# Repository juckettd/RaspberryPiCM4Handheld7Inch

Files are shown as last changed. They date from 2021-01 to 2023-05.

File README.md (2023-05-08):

# Raspberry Pi CM4 Handheld 7 - Aegis"

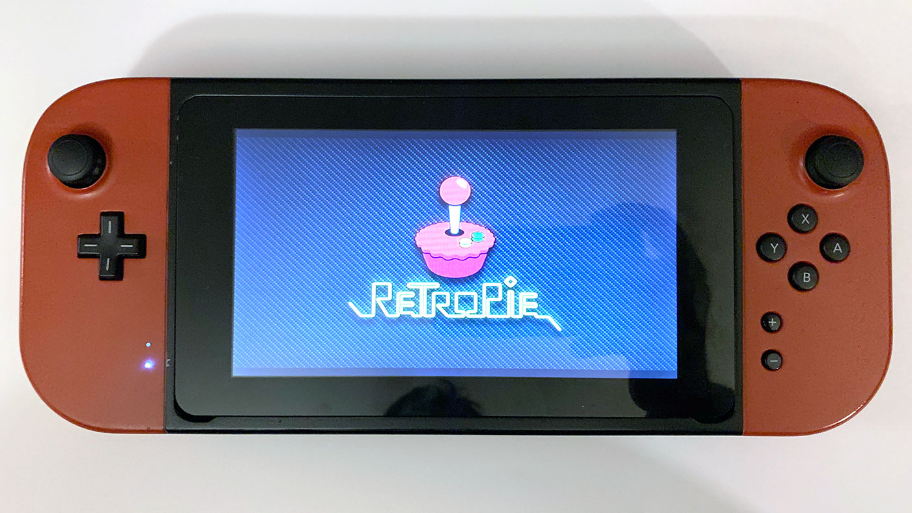
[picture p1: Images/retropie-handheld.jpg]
RetroPie running on Raspberry Pi CM4 Handheld
<p align="center"></p>

A repository for the Aegis, a 7" Raspberry Pi CM4 handheld device.

NOTE: This is still a work in progress. The design has been finalized but I'm still working on the instructions, therefore there might be steps that are missing at this moment.

## Summary

The Aegis is a DIY handheld that uses a 3D printed case with a Raspberry Pi CM4 and the official Raspberry Pi 7" screen. The official Raspberry Pi screen was chosen because it uses the DSI port on the Raspberry Pi and the CM4 could fit on either side of the display board. While a Raspberry Pi 4 might have fit inside the case, that was eventually designed, a custom carrier board was used to place the ports in the desired locations. To facilitate the controller portion of the device, the Wii U buttons and joysticks were used. This made it easy to use the button sub-assemblies so that the same tactile feel of the buttons could be maintained. The 3D printed case was based on the Wii U Gamepad but still designed from the ground up to fit the 7" screen and the custom circuit board. Finally, the whole thing was assembled with speakers and rumble motors to complete the handheld.

## Building the Handheld

To build the handheld you will need the items listed as required in the Bill of Materials along with the following tools:

Reflow Station or Reflow Oven<br/>
Solding Iron<br/>
Solder Paste<br/>
Tweezers<br/>
Small Philips Screw Driver<br/>
Small Flathead Screw Driver<br/>
Super Glue (preferrably CA glue with Accelerator)

There are items in the Bill of Materials that are listed as optional (such as the Wifi chip). These items are not required to get a working device but can be used if desired. At this time I will not provide directions on how to use the optional components so use at your discretion.

### Assembling the Circuit Board

The custom circuit boards are provided as eagle files in this repository. This includes the schematic, board layout, and the gerber files. 

To get the boards printed, a manufacturing facility is required. The website jlcpcb.com was used to print the 2 circuit board prototypes for the design. The larger of the two boards uses 4 layers, and the smaller one uses only 2 layers. It is recommended to also get the stencils with the boards so that applying the solder paste becomes much easier.

Once the boards have been received you will need to assemble the circuitry on the boards. This is done by getting all of the components provided in the bill of materials in the "PCB Components" sheet. Each item has a provided Link to where the item can be acquired along with the price at the time of the assembly of the prototype. After acquiring all of the components, use the stencil to apply solder paste to the circuit boards and then use tweezers to place each component. A reflow oven or reflow station should then be used to melt the solder paste and adhere the components. Lastly, any through hole components were then added on the using a soldering iron. 

Note: The teensy that is soldered to the board using the through holes. However, there are 4 pads that are located near the USB connector of the Teensy on the custom circuit board. They are the VBUS, D+, D-, and GND connections. I included the VBUS and GND connections as backups but they are not needed as the power and ground comes from the pins. But the D+, D- connections need to be connected to the teensy. On the underside of the teensy there are 4 pads that are in about the same location, a wire or some other form of connection is needed to connect the D+ from the teensy to the D+ on the custom circuit board, do the same with the D- connection.

While anyone who has experience with circuit boards will have their own method for assembling these boards I used the following steps and it is what I recommend for anyone without experience and a reflow oven (but a reflow station is required):
1. Using the stencil, put solder paste on the larger of the two boards on the side with a majority of the components
2. Place all of the surface mount components on that side of the board
3. Use a reflow station and heat the underside of the board until the solder paste on the top side melts to adhere the components. A tool to prop up the PCB comes in handy here. In my opinion this part is essential as some of the components are plastic and the hot air coming out of a reflow station can melt them.
4. Use a soldering iron to clean up an connections that didn't connect completely (You can watch youtube videos on how to do this, just search for solding iron and surface mount components)
5. Flip the board over and redo steps 1-4 for the underside of the board. Since these components are larger I just used the a soldering iron for all of the components, but the same procedure with the reflow station can be used. Just be careful with the hot air hitting components you have already put down, as they can fall off if the solder paste melts again.
6. Perform 1-5 for the second board and the few surface mount components that are on that board
7. Add all of the through hole items to both boards with a soldering iron (again youtube is your friend)

### Install Teensy Code

Before (or after) the circuit board has been assembled the teensy code needs to be pushed to the teensy. The teensy code is provided in the repo and you will need to follow the instructions on the teensy website for pushing code. Make sure that you set the board type to "XInput" otherwise it won't be seen as a XBox 360 Controller.

### 3D Printed Case

The files provided here and on Thingiverse are STL files for the case. They are printed in sections so that a printer with a standard bed size of 220mm x 220mm can be used print the case (I also provided the pieces combined for larger printers). Once they are printed they will have to be cleaned up and then glued together. Depending on which angle you choose to print the parts the cleanup step could be more or less cumbersome for the remove of support and getting good glue joints. I choose to print everything with flat surfaces on the bed to keep the post processing steps as easy as possible.

Once everything is glued together then no post processing is technically required to assemble the device. However, I chose to use filler, sand paper, and paint to get a really clean looking finish. The level of detail you desire on your handheld will be up to you based on how much effort you want to devote. Refer to youtube for how to sand and paint a 3D printed piece. However, try to keep the inside of the device as paint free as possible as the internal structure is already at the correct dimensions for the internal components.

I would also sand down the holes where the buttons will be located as they will to be rough from the 3D printing process. This can cause the buttons to stick.

Thingiverse link:
https://www.thingiverse.com/thing:4789405

### Assembly

Once the case and the PCB have been built and are ready to go the handheld can be assembled.

See the assembly instructions file provided with detailed instructions and pictures.

## Software

The carrier board was designed with the option of either using the CM4 lite or the CM4 with onboard memory. If the lite is used then a micro SD card is required. Follow the instructions on the official Raspberry Pi website or the RetroPie website to get the desired OS installed on the micro SD card. If the lite is not used then the internal memory can be loaded by removing the panel on the back of the handheld held and flipping the switch to the "ON" position. You can then use the micro USB port to load the CM4. Please refer to the official Raspberry Pi website on these steps. Once the OS is loaded then unplug the cable and flip the switch back to the off position.

### /boot/config.txt

Regardless of which CM4 you use and which method is used to load the OS, you will need to add the following lines to the /boot/config.txt file. These are also listed in the /Config/boot/config.txt file in this repository:

dtoverlay=dwc2,dr_mode=host<br/>
gpu_mem_256=128<br/>
gpu_mem_512=256<br/>
gpu_mem_1024=256<br/>
force_turbo=1<br/>
h264_freq=333

The lines above will optimize the graphics for Moonlight (if you choose to use it to stream PC games) and will enable USB 2.0 on the device to get the Teensy and external USB ports working.

### First Boot

For the first boot you will need to plug in a HDMI cord into the HDMI mini port. This is required since the screen won't work yet. Once it boots you need to connect to Wifi or Ethernet through whatever OS you have installed and run the following commands (also listed in the Config folder):

sudo apt install python3-gpiozero<br/>
sudo apt install python3-smbus<br/>
sudo wget https://goo.gl/iiVxuA -O /boot/dt-blob.bin

These will install required packages for a system monitor script and will also install the dt-blob.bin file to get the screen working. Once this is complete reboot the handheld and unplug the HDMI cord. The device will automatically switch to the screen on the reboot.

### System Setup

After the first boot and subsequent reboot you can either use git to download the items from the Config folder in this repository or you can copy the files to a USB stick and load them through the USB ports. Once on your Raspberry Pi, navigate to wherever you have loaded the files and run the setup.sh script as follows:

sudo bash ./setup.sh

This script will install files onto your Raspberry Pi to handle a series of things including:

Provide a startup script to detect when the HDMI cord is plugged in and switch to that output<br/>
Enable the buttons on the device to work<br/>
Enable sound through the speakers<br/>
Generating an overlay on the screen to give battery life, wifi status, bluetooth status, etc...<br/>
Provide a safe shut down proceedure for when the power button is pressed<br/>

Once the setup script is run the files you downloaded may be deleted.

## Have Fun

At this point the device should be fully up and running on whatever OS you decided to use. I suggest you start playing games and have fun :)

## Pictures/Videos

Images of the prototype are included if you want to see what a final version can look like and here is a list of youtube links for demoes on the device in operation:

Raspberry Pi CM4 Handheld - PC Games Demo
https://youtu.be/qqAcT7MvEfQ

Raspberry Pi CM4 Handheld - Pixel Desktop Logout
https://youtu.be/YUHz1qglbvk

Raspberry Pi CM4 Handheld - Touchscreen Demo
https://youtu.be/fQMbkvToMkI

Raspberry Pi CM4 Handheld - Youtube Video Showing Sound Quality
https://youtu.be/o1zs3FDNwGw

Raspberry Pi CM4 Handheld - Donkey Kong Country 2
https://youtu.be/sit6ItH9wHg

Raspberry Pi CM4 Handheld - Prototype Test
https://youtu.be/XAPKUmwa3sU

## Credits

To get the script and overlay down I took parts of the following work and adapted it to what I needed. But these projects deserve most of the credit for what they already did.

GBZ_Overlay 
https://github.com/d-rez/gbz_overlay

Pngview
https://github.com/AndrewFromMelbourne/raspidmx/tree/master/pngview

Safe shutdown script
https://github.com/crcerror/ES-generic-shutdown/blob/master/multi_switch.sh

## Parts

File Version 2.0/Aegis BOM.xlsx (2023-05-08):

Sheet: PCB Components
Item | Component | Qty | Price | Total | Link
Power Items
Battery Charging IC | BAT_CHR | 1 | $3.76 | $3.76 | https://www.digikey.com/product-detail/en/texas-instruments/BQ25895RTWT/296-41132-1-ND/5218172
5V Boost IC | 5V_REG | 1 | $2.68 | $2.68 | https://www.digikey.com/en/products/detail/texas-instruments/TPS61030PWPR/550685
3.3V Buck/Boost IC | 3.3V_REG | 1 | $2.34 | $2.34 | https://www.digikey.com/en/products/detail/texas-instruments/TPS63001DRCR/1016512
2 pin Connection Header | BAT_CONN | 1 | $0.17 | $0.17 | https://www.digikey.com/product-detail/en/jst-sales-america-inc/S2B-XH-A-LF-SN/455-2257-ND/1651055
2 pin Connection Housing | BAT_PLUG | 1 | $0.10 | $0.10 | https://www.digikey.com/product-detail/en/jst-sales-america-inc/XHP-2/455-2266-ND/555485
Jumper Wires | BAT_WIRES | 1 | $0.76 | $0.76 | https://www.digikey.com/product-detail/en/jst-sales-america-inc/ASXHSXH22K152/455-3240-ND/6684931
USB-C Socket (PWR) | USB_PWR | 1 | $1.26 | $1.26 | https://www.digikey.com/en/products/detail/adam-tech/USB-C31-S-RA-CS1D-BK-T-R/9832218
Fuel Gauge | FUELGAUGE | 1 | $3.15 | $3.15 | https://www.digikey.com/en/products/detail/analog-devices-inc-maxim-integrated/MAX17055ETB-T/7200799
Audio Items
UDA1334A | AUDIO_DAC | 1 | $0.25 | $0.25 | https://www.aliexpress.com/item/33049485687.html?spm=a2g0s.9042311.0.0.1b124c4d3HPSEF
MAX98306ETD+T | AUDIO_AMP | 1 | $1.91 | $1.91 | https://www.digikey.com/en/products/detail/maxim-integrated/MAX98306ETD-T/2708795
Headphone Jack | AUDIO_PLUG | 1 | $1.38 | $1.38 | https://www.digikey.com/product-detail/en/adam-tech/ASJ-192-Y-T-R/2057-ASJ-192-Y-T-RCT-ND/9833145
USB Items
USB 2 Port Stacked | USB_CONN | 1 | $5.76 | $5.76 | https://www.digikey.com/en/products/detail/w%C3%BCrth-elektronik/614108646521/11627306
USB Hub 4-port | USB_HUB | 1 | $3.05 | $3.05 | https://www.digikey.com/en/products/detail/microchip-technology/USB2514BT-I-M2/9923870
USB Current Limit | USB_CURLIM | 1 | $0.42 | $0.42 | https://www.digikey.com/en/products/detail/diodes-incorporated/AP22653W6-7/10481188
24MHz Crystal | CLK_24M | 1 | $0.39 | $0.39 | https://www.digikey.com/en/products/detail/ecs-inc/ECS-240-9-33B-CTP-TR/12349443
USB POE Protection | USB_POE | 1 | $0.79 | $0.79 | https://www.digikey.com/en/products/detail/texas-instruments/TPD4EUSB30DQAR/2503665
USB Host/Slave Switch | USB_SWI | 1 | $0.60 | $0.60 | https://www.digikey.com/en/products/detail/on-semiconductor/FSUSB42MUX/2036916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
USB Micro Input | USB_IN | 1 | $0.76 | $0.76 | https://www.digikey.com/en/products/detail/gct/USB3131-30-0230-A/9859642
RPI Boot Switch | RPI_BOOT_SW | 1 | $0.91 | $0.91 | https://www.digikey.com/en/products/detail/omron-electronics-inc-emc-div/A6TN-1104/2754763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
HDMI Items
HDMI Socket | HDMI_CONN | 1 | $1.73 | $1.73 | https://www.digikey.com/en/products/detail/cnc-tech/2001-1-2-21-00-BK/4867021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
HDMI Current Limit | HDMI_CURLIM | 1 | $0.51 | $0.51 | https://www.digikey.com/en/products/detail/diodes-incorporated/AP2331W-7/4251553
LCD Items
FPC Connector | LCD_CONN | 1 | $0.95 | $0.95 | https://www.digikey.com/en/products/detail/te-connectivity-amp-connectors/1-84952-5/2272419
Micro SD Items
Micro SD Socket | MICROSD | 1 | $2.41 | $2.41 | https://www.digikey.com/product-detail/en/molex/5033981892/WM11190CT-ND/5230912
Micro SD Power Switch | MICROSD_SWI | 1 | $1.52 | $1.52 | https://www.digikey.com/en/products/detail/richtek-usa-inc/RT9742GGJ5/5880519
Ethernet
Ethernet Port | ETH_CONN | 1 | $8.21 | $8.21 | https://www.digikey.com/en/products/detail/kycon-inc/GLPLX-SMT-188S7-QQ-Y-G/9990208
Board Connectors
Mezzanine Connector (RP4) | RPI_PINR1-100, RPI_PINS101-200 | 2 | $1.73 | $3.46 | https://www.digikey.com/en/products/detail/hirose-electric-co-ltd/DF40C-100DS-0-4V-51/1969476
Mezzanine Connector (Top Ports Board) | BOARD_CONN_2 | 1 | $1.36 | $1.36 | https://www.digikey.com/en/products/detail/panasonic-electric-works/AXT530124/1986604
Mezzanine Header (Main Board) | BOARD_CONN_1 | 1 | $1.86 | $1.86 | https://www.digikey.com/en/products/detail/panasonic-electric-works/AXT630124/1986595
Speaker/Motor Connector | SPK_CONN, MOT_CONN | 2 | $0.65 | $1.30 | https://www.digikey.com/en/products/detail/jst-sales-america-inc/S4B-ZR-SM4A-TF-LF-SN/926602
Speaker/Motor Jumper | SPK_WIRE, MOT_WIRE | 2 | $1.79 | $3.58 | https://www.digikey.com/en/products/detail/jst-sales-america-inc/A04ZR04ZR28H305A/6009406
Fan Connector | FAN_CONN | 1 | $1.25 | $1.25 | https://www.digikey.com/en/products/detail/te-connectivity-amp-connectors/282834-2/1150135
LCD Power Connector | LCD_PWR_CONN | 1 | $0.19 | $0.19 | https://www.digikey.com/en/products/detail/amphenol-icc-fci/68016-402HLF/1658021
Button Connector | BUTL_CONN, BUTR_CONN | 2 | $1.73 | $3.46 | https://www.digikey.com/product-detail/en/hirose-electric-co-ltd/FH52-10S-0-5SH/H126109CT-ND/9489678
Buttons
Buttons | BUT_PWR, BUT_MISC, BUT_VOL_UP, BUT_VOL_DOWN | 4 | $0.65 | $2.60 | https://www.digikey.com/en/products/detail/c-k/KSS331GLFS/417674?s=N4IgTCBcDaINIGUEGZkEYDiAZAYgkAugL5A
LED
Amber LED | LED1, LED2 | 2 | $0.46 | $0.92 | https://www.digikey.com/en/products/detail/bivar-inc/SM0805AC/3095524
Buffer Component | BUF1, BUF2, BUF3 | 3 | $0.27 | $0.81 | https://www.digikey.com/en/products/detail/diodes-incorporated/74LVC1G07SE-7/2356534
Accelerometer (Optional)
Accelerometer | ACCEL | 1 | $3.04 | $3.04 | https://www.digikey.com/en/products/detail/nxp-usa-inc/MMA8451QR1/2508916
Transistors
Transistor NPN | TR1, TR2, TR3, TR4, TR5, TR6, TR7 | 7 | $0.42 | $2.94 | https://www.digikey.com/en/products/detail/diodes-incorporated/DMG2302UKQ-7/9769911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
Diodes
Diode 40V 2A | D1, D2, D3 | 3 | $0.41 | $1.23 | https://www.digikey.com/product-detail/en/diodes-incorporated/SDM2U40CSP-7B/SDM2U40CSP-7BDICT-ND/6013037
Resistors
Res 10K (603) | R1, R2, R3, R4, R5, R6, R7, R8, R9, R10, R11, R12, R13, R14, R15, R16, R18, R19, R20, R25, R29, R51 | 22 | $0.10 | $2.20 | https://www.digikey.com/product-detail/en/yageo/RC0603FR-0710KL/311-10-0KHRCT-ND/729827
Res 1K (603) | R21, R22 | 2 | $0.13 | $0.26 | https://www.digikey.com/en/products/detail/vishay-beyschlag-draloric-bc-components/MCT06030C1001FP500/2607821
Res 2.2K (603) | R23, R24, R39, R40 | 4 | $0.10 | $0.40 | https://www.digikey.com/en/products/detail/yageo/RC0603FR-072K2L/727016
Res 12K (603) | R26, R27 | 2 | $0.10 | $0.20 | https://www.digikey.com/en/products/detail/yageo/RT0603DRE0712KL/1074561
Res 15K (603) | R28 | 1 | $0.10 | $0.10 | https://www.digikey.com/en/products/detail/yageo/RC0603FR-0715KL/726953
Res 36K (603) | R30, R31, R32, R33 | 4 | $0.10 | $0.40 | https://www.digikey.com/en/products/detail/yageo/RC0603FR-0736KL/727179
Res 100K (603) | R34, R35 | 2 | $0.10 | $0.20 | https://www.digikey.com/en/products/detail/yageo/RT0603DRE07100KL/1074518
Res 180K (603) | R36 | 1 | $0.10 | $0.10 | https://www.digikey.com/en/products/detail/yageo/RC0603FR-07180KL/726995
Res 220K (603) | R37, R38 | 2 | $0.10 | $0.20 | https://www.digikey.com/en/products/detail/yageo/RC0603FR-07220KL/727062
Res 10 (603) | R54 | 1 | $0.26 | $0.26 | https://www.digikey.com/en/products/detail/yageo/AT0603FRE0710RL/5138642
Res 47 (603) | R41 | 1 | $0.10 | $0.10 | https://www.digikey.com/en/products/detail/yageo/RT0603DRE0747RL/1074878
Res 100 (603) | R17, R42, R43, R52, R53 | 5 | $0.17 | $0.85 | https://www.digikey.com/en/products/detail/yageo/RT0603DRD07100RL/1035412
Res 120 (603) | R45 | 1 | $0.10 | $0.10 | https://www.digikey.com/product-detail/en/yageo/RC0603FR-07120RL/311-120HRCT-ND/729867
Res 1.65M (603) | R46 | 1 | $0.10 | $0.10 | https://www.digikey.com/en/products/detail/yageo/RC0603FR-071M65L/5918265
Res 0 (603) | R47, R48, R49, R50 (Pick 1 for Gain) | 1 | $0.10 | $0.10 | https://www.digikey.com/en/products/detail/yageo/RC0603JR-070RL/726675
Res 0.01 (603) | R44 | 1 | $0.93 | $0.93 | https://www.digikey.com/en/products/detail/yageo/PF0603FRE7T0R01Z/2827678
Capacitors
Cap 100uF (603) | C1 | 1 | $0.78 | $0.78 | https://www.digikey.com/en/products/detail/avx-corporation/F980J107MMAAXE/5957626
Cap 10uF (603) | C2, C3, C4, C5, C6, C7, C8, C9, C10, C11, C12, C13, C14, C15, C16, C17, C18, C19, C20, C21, C22, C23, C29, C57 | 24 | $0.20 | $4.80 | https://www.digikey.com/en/products/detail/murata-electronics/GRM188R61A106KE69D/5026392
Cap 1uF (603) | C24, C25, C26, C27, C28 | 5 | $0.25 | $1.25 | https://www.digikey.com/product-detail/en/murata-electronics/GCJ188R71E105KA01D/490-14409-1-ND/6606870
Cap 0.1uF (603) | C30, C31, C32, C33, C34, C35, C36, C37, C38, C39, C40, C41, C42, C43, C44, C45, C59, C60 | 18 | $0.10 | $1.80 | https://www.digikey.com/en/products/detail/samsung-electro-mechanics/CL10B104KB8NNNL/3894274
Cap 0.01uF (603) | C46, C47 | 2 | $0.10 | $0.20 | https://www.digikey.com/en/products/detail/samsung-electro-mechanics/CL10B103KB8NNNC/3886667
Cap 4.7uF (603) | C48 | 1 | $0.24 | $0.24 | https://www.digikey.com/product-detail/en/murata-electronics/GRM188R61C475KAAJD/490-10481-1-ND/5026399
Cap 0.47 uF (603) | C58 | 1 | $0.12 | $0.12 | https://www.digikey.com/en/products/detail/tdk-corporation/C1608X7R1C474K080AC/699790
Cap 47nF (603) | C49 | 1 | $0.24 | $0.24 | https://www.digikey.com/product-detail/en/murata-electronics/GCJ188R71H473KA12D/490-5854-1-ND/2785840
Cap 220uf (1411) | C50 | 1 | $1.20 | $1.20 | https://www.digikey.com/en/products/detail/vishay-sprague/T55B227M6R3C0035/5357197
Cap 2.2uF (603) | C51 | 2 | $0.13 | $0.26 | https://www.digikey.com/product-detail/en/kemet/C0603C225K4PACTU/399-7886-1-ND/3471609
Cap 27pF (603) | C52, C53 | 2 | $0.11 | $0.22 | https://www.digikey.com/en/products/detail/samsung-electro-mechanics/CL10C270JB81PNC/3887905
Cap 16uF (Aluminum Electrolytic) | C54, C55 | 2 | $0.32 | $0.64 | https://www.digikey.com/en/products/detail/panasonic-electronic-components/EEE-HA1C470WR/814162
Cap 0.1uf (805 Film) | C56 | 1 | $0.73 | $0.73 | https://www.digikey.com/en/products/detail/cornell-dubilier-electronics-cde/FCA0805C104M-J2/1924083
Inductors
Ind 2.2uH | L1 | 1 | $1.58 | $1.58 | https://www.digikey.com/product-detail/en/w%C3%BCrth-elektronik/74438357022/732-11201-1-ND/6833660
Ind 6.8uH | L2 | 1 | $0.44 | $0.44 | https://www.digikey.com/product-detail/en/NRS8040T6R8NJGJ/587-2979-1-ND/2666084/?itemSeq=334924146
Ind 2.2uH | L3 | 1 | $0.39 | $0.39 | https://www.digikey.com/en/products/detail/taiyo-yuden/NRS4010T2R2MDGG/2648952
Ferrite Beads
Ferrite (805) | F1, F2 | 2 | $0.10 | $0.20 | https://www.digikey.com/en/products/detail/murata-electronics/BLM18PG471SN1D/1948328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
 | Total | Per Unit
Total x1 | $95.36 | $95.36

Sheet: NonPCB Components
Item |  | Qty | Price | Total | Link
Rumble Motors 2pc (Optional) | RUMBLE | 1 | $8.99 | $8.99 | https://www.amazon.com/gp/product/B07Q71F4L9/ref=ox_sc_act_title_2?smid=A1TBJFOKESMIUW&psc=1
Battery 6000 mAh | BAT | 1 | $12.12 | $12.12 | https://www.aliexpress.com/item/32909360073.html?scm_id=1007.13339.169870.0&scm-url=1007.13339.169870.0
Speakers | SPEAKER | 2 | $3.86 | $7.72 | https://www.digikey.com/en/products/detail/cui-devices/CDS-27204/5355541
Teensy LC | TEENSY | 1 | $11.65 | $11.65 | https://www.pjrc.com/teensy/teensyLC.html
Teensy Header | HEADERS | 1 | $0.57 | $0.57 | https://www.digikey.com/en/products/detail/sullins-connector-solutions/PREC040SABN-RC/2775014
Wifi/Bluetooth Antenna (Optional) | ANT | 1 | $4.29 | $4.29 | https://www.digikey.com/product-detail/en/laird-connectivity-inc/001-0016/001-0016-ND/5305252
Fan (aliexpress, RFB4505) | FAN | 1 | $9.08 | $9.08 | https://www.aliexpress.com/item/32910258011.html?spm=a2g0s.9042311.0.0.1b124c4d3HPSEF
Heatsink | HEATSINK | 4 | $0.80 | $3.20 | https://www.digikey.com/product-detail/en/aavid-thermal-division-of-boyd-corporation/501200B00000G/HS227-ND/265412
Heatpipe 11.2x3.5x100mm | HEATPIPE | 1 | $2.89 | $2.89 | https://www.digikey.com/product-detail/en/advanced-thermal-solutions-inc/ATS-HP-F7L100S70W-016/ATS2156-ND/5049699
LED Lens | LENS | 2 | $1.81 | $3.62 | https://www.digikey.com/en/products/detail/bivar-inc/PLPC1-9MM/5721855?s=N4IgTCBcDaIAoBk4GECMBaAnAWWyAugL5A
Charger Heatsink | HEATSINK2 | 1 | $0.40 | $0.40 | https://www.digikey.com/en/products/detail/assmann-wsw-components/V5618A/3511413
7.0" Official Raspberry Pi Touchscreen |  | 1 | $60.00 | $60.00 | https://www.newark.com/raspberry-pi/raspberrypi-display/display-7-touch-screen-rpi-sbc/dp/49Y1712
Raspberry PI CM4 |  | 1 | $35.00 | $35.00 | https://www.pishop.us/product/raspberry-pi-compute-module-4-wireless-2gb-lite-cm4102000/
Wii U Button and Contacts |  | 1 | $4.99 | $4.99 | https://www.ebay.com/itm/OEM-Full-Set-Replacement-Button-for-Nintendo-Wii-U-Gamepad-Controller-Black/263927328731
Wii U Analog Joystick |  | 1 | $9.51 | $9.51 | https://www.ebay.com/itm/Repair-Right-Left-Set-Joystick-3D-Analog-Cap-Screwdrivers-Tool-for-Wii-U/183793372505
Wii U Left/Right Button Brackets |  | 1 | $6.98 | $6.98 | https://www.ebay.com/itm/Left-Right-Keypad-Ribbon-Flex-Cable-with-Bracket-For-Wii-U-Pad-Controller/172990188598
Wii U Shoulder Buttons |  | 1 | $7.99 | $7.99 | https://www.ebay.com/itm/Nintendo-Wii-U-Gamepad-controller-Black-Left-Right-ZL-ZR-Trigger-Button-Parts/152308442396
Raspberry PI 4 Heat Sinks |  | 1 | $5.97 | $5.97 | https://www.amazon.com/gp/product/B07ZLZRDXZ/ref=ppx_yo_dt_b_asin_title_o00_s00?ie=UTF8&psc=1
Hardware
All Screw Set for x1 product |  |  | 1 | $6.90 | https://www.amazon.com/gp/product/B01GE9AK7I/ref=ppx_yo_dt_b_asin_title_o04_s00?ie=UTF8&psc=1
Total |  |  |  | $194.97

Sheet: Tools
Tools | Qty | Price | Total | Link
Double Sided Tape | 1 | $15.99 | $15.99 | https://www.amazon.com/gp/product/B019OQ4YWK/ref=ppx_yo_dt_b_asin_title_o02_s00?ie=UTF8&psc=1
Thermal Adhesive Tape | 1 | $12.99 | $12.99 | https://www.amazon.com/gp/product/B06ZY1JNJV/ref=ppx_yo_dt_b_asin_title_o07_s00?ie=UTF8&psc=1
Kaplan Tape | 1 | $8.99 | $8.99 | https://www.amazon.com/gp/product/B07S1Z877Q/ref=ppx_yo_dt_b_asin_title_o07_s00?ie=UTF8&th=1
Dust Filter | 1 | $31.99 | $31.99 | https://www.amazon.com/DustEND-Premium-Dust-Filter-Material/dp/B0771PX116
Speaker Cloth | 1 | $13.99 | $13.99 | https://www.amazon.com/gp/product/B07YZHBHKC/ref=ppx_yo_dt_b_asin_title_o07_s00?ie=UTF8&psc=1
Screws | 1 | $6.90 | $6.90 | https://www.amazon.com/gp/product/B01GE9AK7I/ref=ppx_yo_dt_b_asin_image_o03_s00?ie=UTF8&psc=1
Wire 30 AWG | 1 | $12.99 | $12.99 | https://www.amazon.com/StrivedayTM-Flexible-Silicone-electronic-electrics/dp/B01LH1G2IE
Copper Plate | 1 | $6.83 | $6.83 | https://www.aliexpress.com/item/33052616618.html
Total |  |  | $110.67

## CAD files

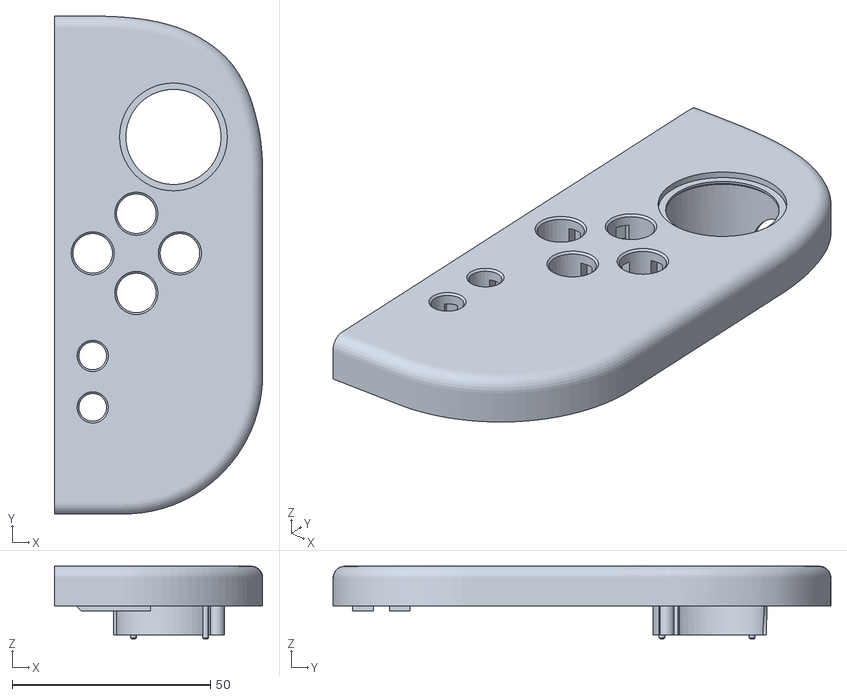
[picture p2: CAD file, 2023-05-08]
Version 2.0/CAD/Front R.stl
52.6 x 125.7 x 18.3

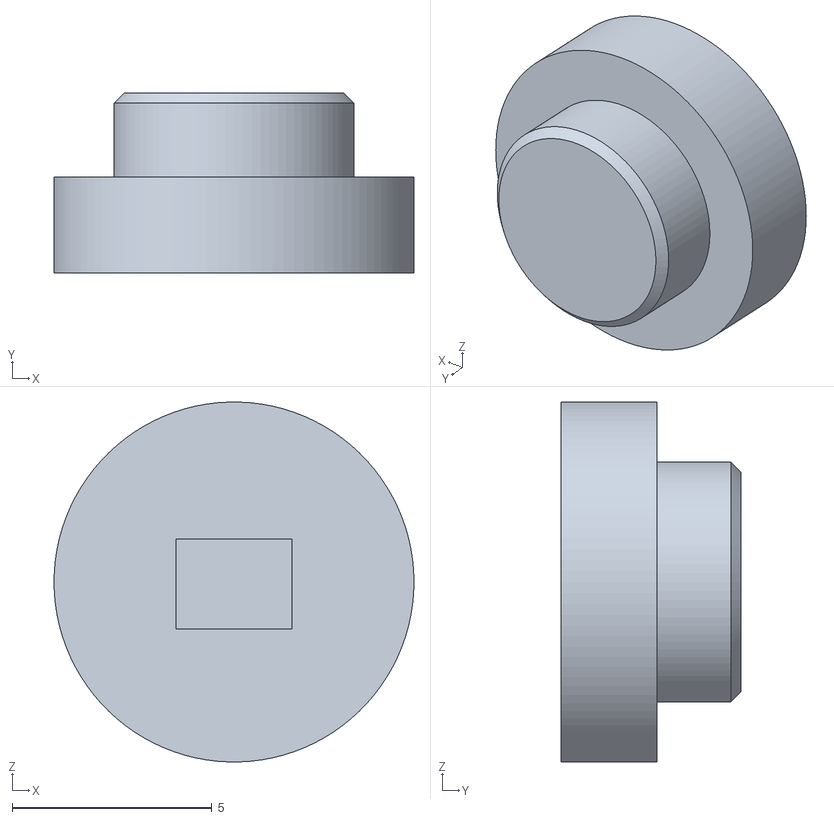
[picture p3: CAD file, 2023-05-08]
Version 2.0/CAD/Misc Cap.stl
9.00 x 4.50 x 9.00

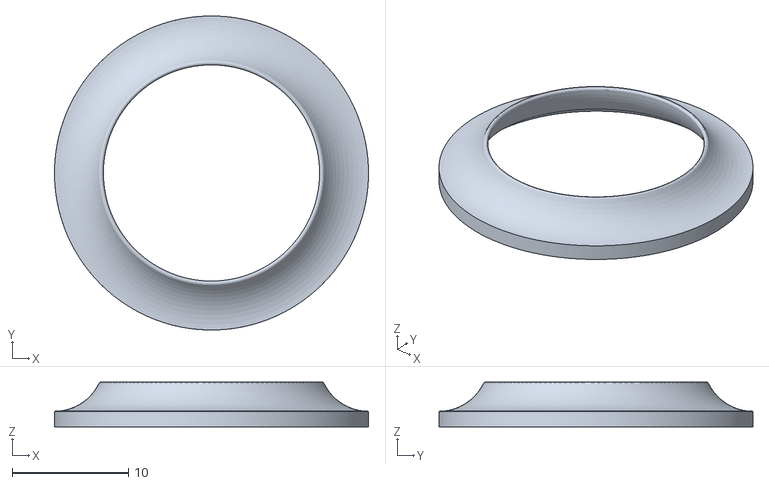
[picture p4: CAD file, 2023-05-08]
Version 2.0/CAD/Front L Bezel.stl
27.0 x 27.0 x 3.86

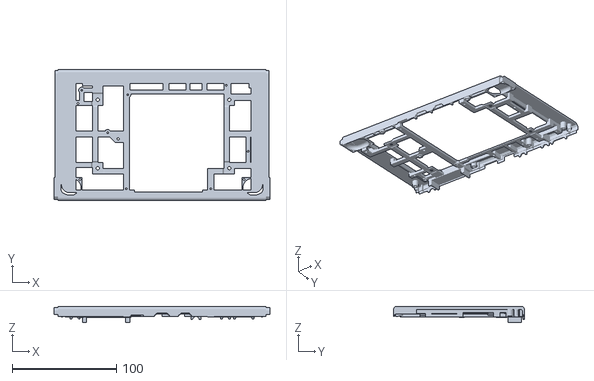
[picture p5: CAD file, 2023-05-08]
Version 2.0/CAD/Front.stl
207.2 x 125.7 x 15.7

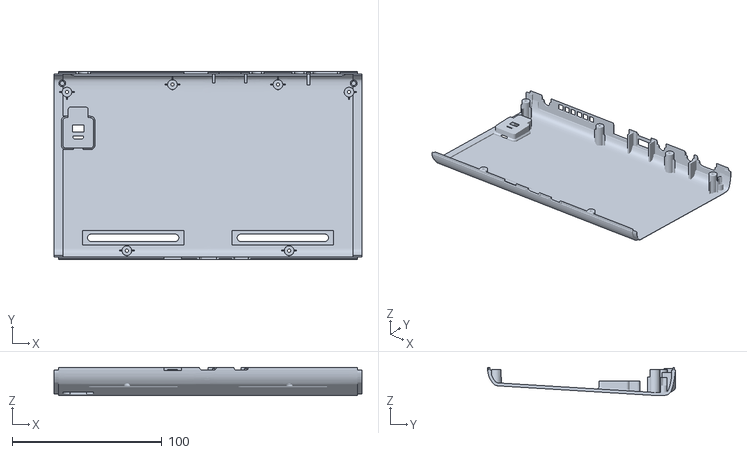
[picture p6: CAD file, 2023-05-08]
Version 2.0/CAD/Back C.stl
205.9 x 125.7 x 18.9

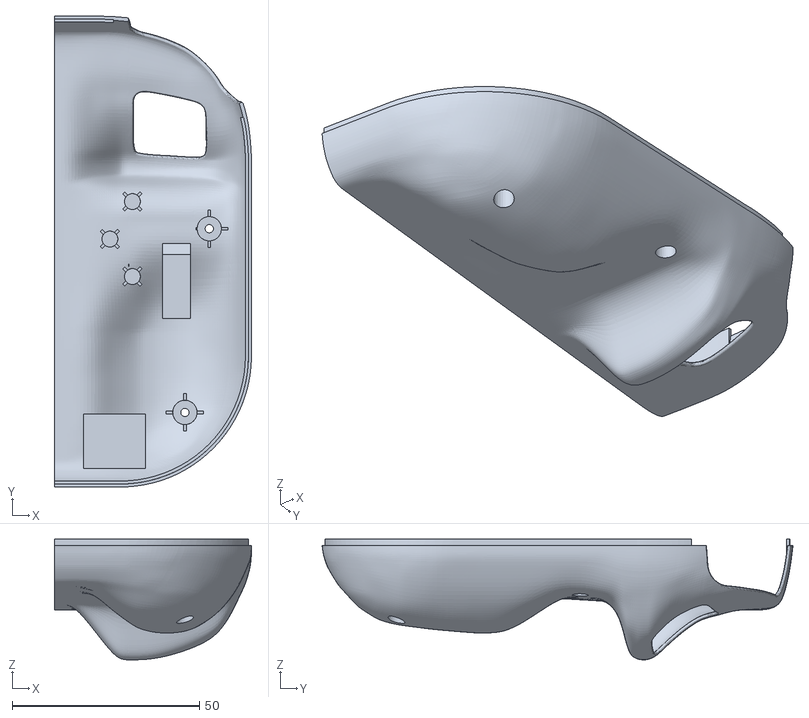
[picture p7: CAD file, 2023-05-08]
Version 2.0/CAD/Back R.stl
52.6 x 125.6 x 32.2

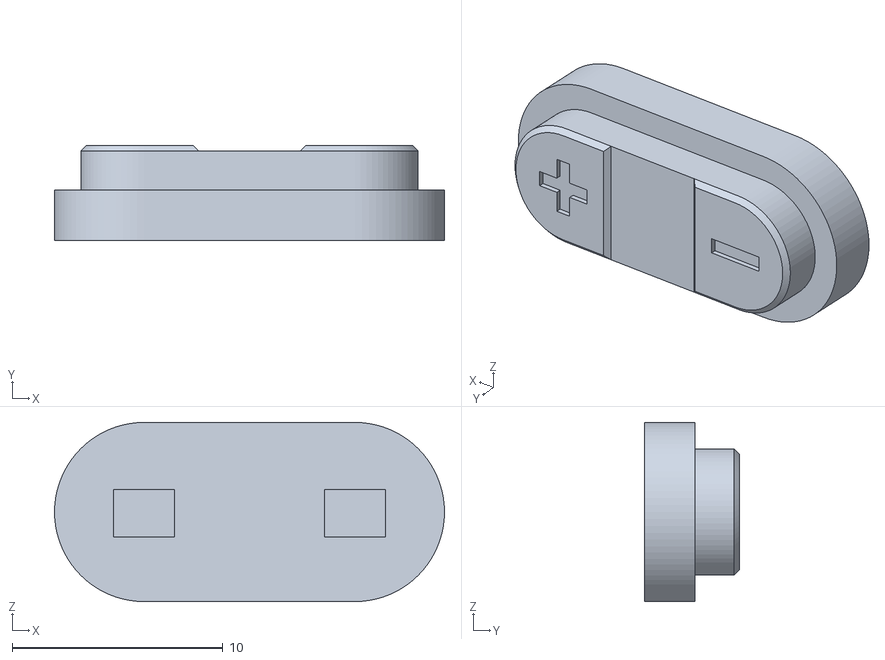
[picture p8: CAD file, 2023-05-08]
Version 2.0/CAD/Volume Cap.stl
18.5 x 4.50 x 8.50

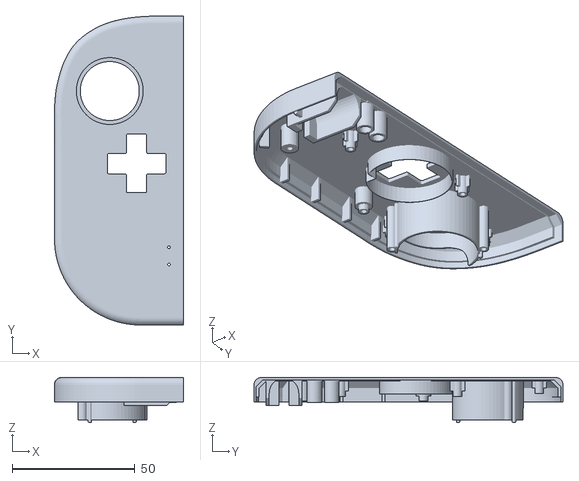
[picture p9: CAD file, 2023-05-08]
Version 2.0/CAD/Front L.stl
52.6 x 125.7 x 18.3

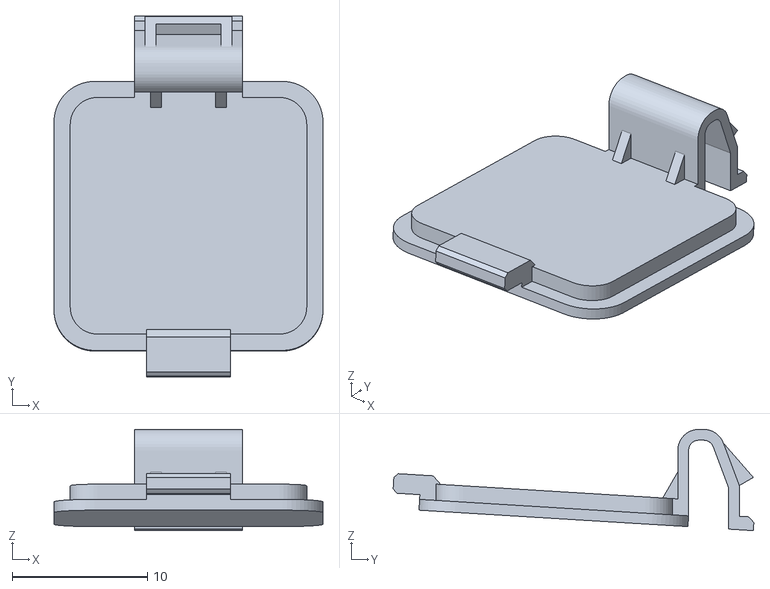
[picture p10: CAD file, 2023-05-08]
Version 2.0/CAD/Back Usb Cover.stl
19.9 x 26.7 x 7.49

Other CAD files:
Version 2.0/CAD/Front R Bezel.stl
Version 2.0/CAD/Back L.stl
Version 2.0/CAD/Power Cap.stl
Version 1.0/CAD/Front C.stl

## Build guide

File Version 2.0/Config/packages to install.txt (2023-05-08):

dt-blob.bin (screen)
wiringpi (update for CM4)

sudo wget https://datasheets.raspberrypi.com/cmio/dt-blob-disp1-only.bin -O /boot/dt-blob.bin
move dt-blob.bin to /boot/ directory

git clone https://github.com/WiringPi/WiringPi
cd WiringPi
./build

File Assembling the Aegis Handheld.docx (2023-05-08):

# Assembling the Aegis Handheld

## Step 1: Install the wires to the Joysticks

Find the connectors that are used to connect to the joysticks. Cut off the connectors that do not connect to the joystick side. Then solder the wires to the underside of the circuit board on the left- and right-hand side. To figure out the ordering of the wires follow these steps and refer to Figures 1 and 2:

1. Put the circuit board down on a table face up.
2. Insert the connectors into the joysticks with the one side cut off.
3. Put the joysticks upside down on the left- and right-hand side of the board making sure the connectors face towards the circuit board. The joysticks are upside down because that is how they are oriented in the case relative to the circuit board.
4. Align the wires so that the top wire goes to the top pad, the second wire goes to the second pad from the top, and so on and so forth. When the wires are aligned correctly the wires should go straight from the joysticks to the circuit board with no wires crossing.
5. Mark the wires so that you know which wires go to which pad, then turn over the circuit board and joysticks keeping their alignment. Connect the joystick wires to the corresponding pads using a soldering iron. The joysticks can be disconnected before the wires are soldered to make it easier if desired, just don’t lose track of which wire gets connected to which pad.

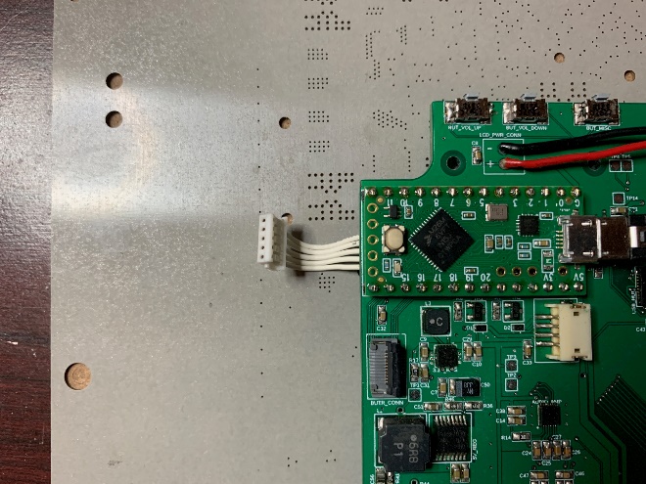
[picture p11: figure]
Joystick Wires Top
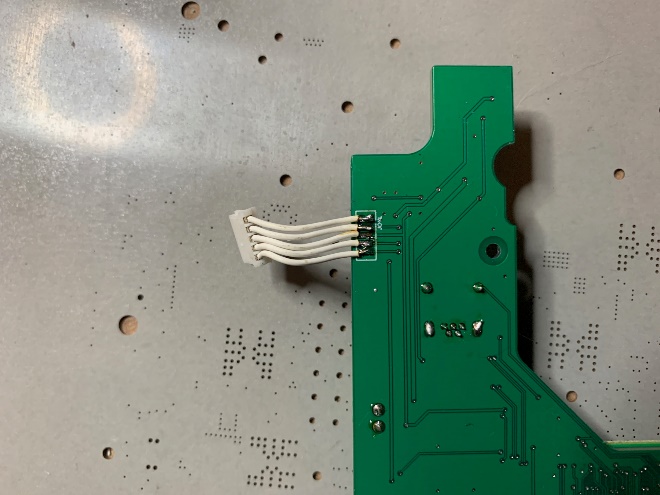
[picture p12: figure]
Joystick Wires Bottom

Figure 1: Joystick Wires Top Figure 2: Joystick Wires Bottom

## Step 2: Install the screen

Start by test fitting the screen to see how well it fits. When inserting the screen make sure the ribbon cables should be at the bottom side of the handheld. The screen should fit flush with the front surface of the handheld without pushing the inner structure at all. If the screen doesn’t fit flush, then use either sandpaper or an X-acto knife to trim down any areas that are needed. This includes edges where the glass sits and the screw mounts. Depending on how the case was printed these areas may need to be trimmed down so that the screen fits correctly. Once the screen fits correctly then add some double-sided tape to the back side of the screen and secure the screen to the case using the tape and the 3M screws. Follow this with some Kapton tape over the screws (as shown in Figure 3) to prevent shorting to the circuit board if the screws touch the board.

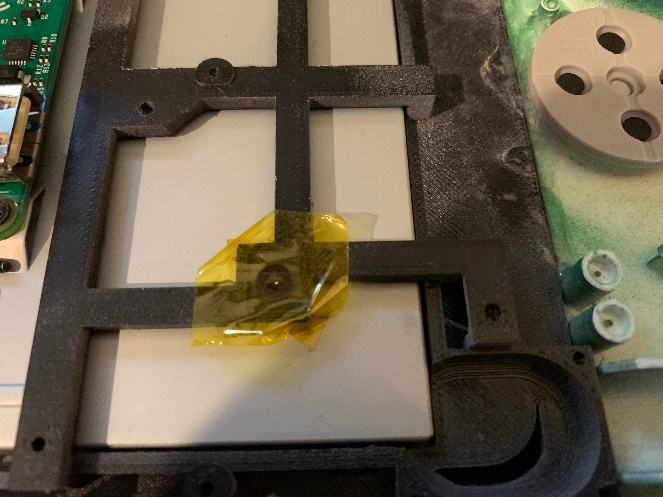
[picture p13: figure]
Figure 1: Kapton Tape Covering Screen Screws

Figure 3: Screen Screws Covered in Kapton Tape

## Step 3: Install the Speaker/Rumble Motors

Place the main circuit board in the case lining it up with the screw holes but don’t screw it down yet. Place the rumble motors in their locations on the left- and right-hand sides with the axles pointing towards the outside of the case. Take one of the wire sets listed as the Speaker/Motor Jumper in the BOM. Using the wires measure the distance from the motor connector on the PCB to the connections on the motors. Make sure the wire is routed down first and then separates at the bottom. Cut the wires to the appropriate length; then using wire strippers and a soldering iron attach the wires to the motors. Make sure that the two left wires go to the left motor and the two right wires go to the right motor. Other than that, it doesn’t matter which wire connects to the +/- terminals of the motor as it doesn’t matter which direction the motor rotates for the rumble feature.

Do the exact same steps with the speakers except it would be better if the same wire of each pair goes to the same terminal on the speaker. This will keep the speakers in sync with each other better. However, this is not required, and you probably won’t notice a difference in the audio.

Once this is complete screw down the speakers and then glue the rumble motors in place. Remove the main circuit board and then route the wires through the path you determined earlier. The route of the wires should go beneath the circuit board to keep it clean, but this is not required. Figures 4 and 5 show an example of the speakers and motors with wires cut to length.

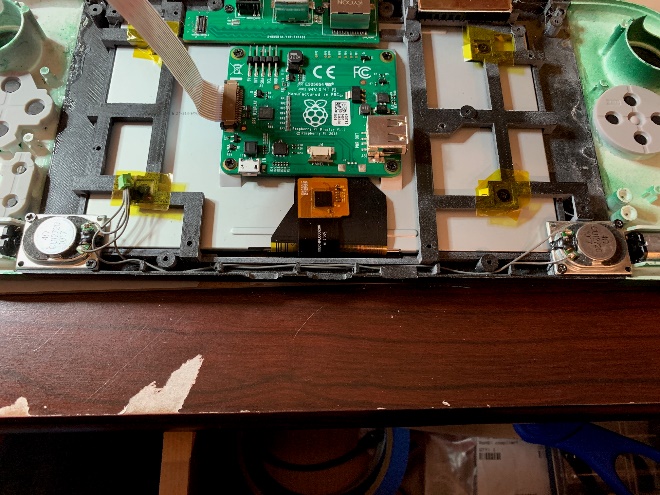
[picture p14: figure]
Speakers with wires routed
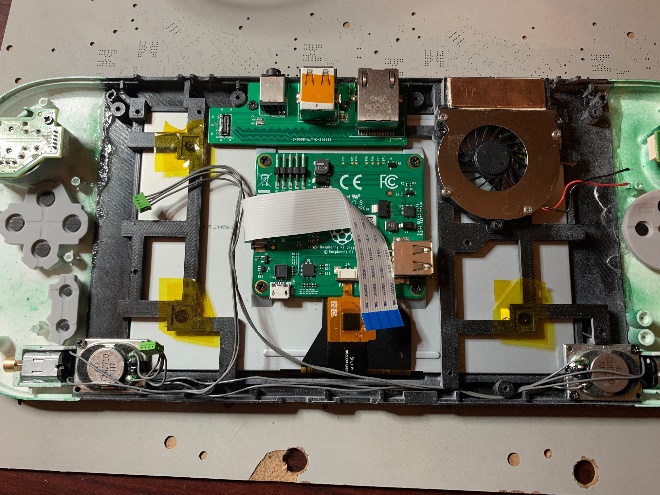
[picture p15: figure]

Figure 4: Speaker Placement and Wires Cut to Length Figure 5: Motor Placement and Wires Cut to Length

## Step 4: Install the Circuit Boards

Before installing the circuit boards, you will need to insert the flat ribbon cable into the official raspberry pi screen display board (as seen in both Figures 4 and 5). You then need to fold over the cable to the right so that it doesn’t get stuck under the main circuit board once it is installed. If you don’t do this first it is very difficult to insert this cable later.

Install the USB/Ethernet circuit board at the top of the case and secure it down with 2M x 3mm screws. The top ports (headphone jack, USB ports, and ethernet ports) should all line up with their corresponding hole in the case as shown in Figure 6.

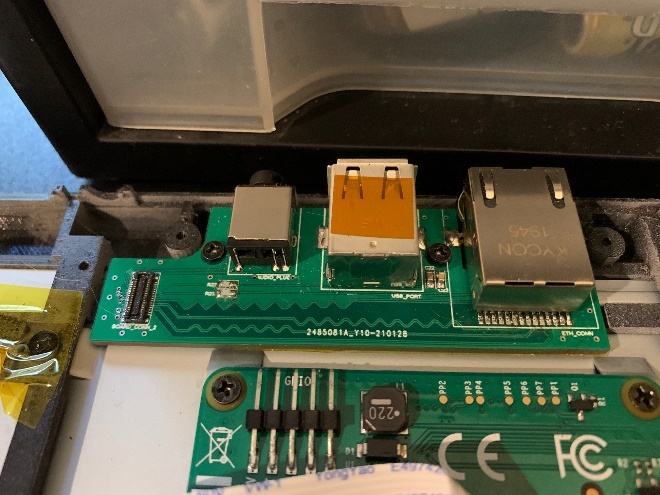
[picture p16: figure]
USB/Ethernet Circuit Board

Figure 6: USB/Ethernet Circuit Board

Install the main circuit board lining up the board with the screw holes again using 2M x 3mm screws. The connectors on the bottom should also line up with the holes in the case. Watch out for the mezzanine connector that connects the two circuit boards together. They should line up perfectly if both circuit boards line up with their screw holes. DO NOT force them together if they are not lining up correctly, you run the risk of damaging the connectors between the boards. Instead try loosening all the screws and to get the boards connected then tighten the screws down. Once it is screwed down connect the speakers and rumble motors. While it can be done later, now would also be a good time to install the raspberry pi if you have not done so already. Refer to Figure 7 for the installed circuit board.

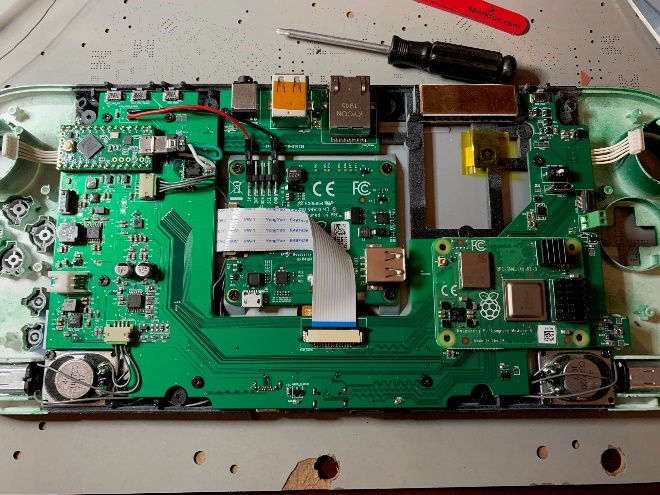
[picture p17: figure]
Main Circuit Board

Figure 7: Main Circuit Board

## Step 5: Connect the Screen

Connect the display board ribbon cable that you folded over previously. There should be two folds in the cable once connected as shown in Figure 7 above.

Follow this by connecting the 5V power and ground to the connector at the top of the display board. This can be done by taking the Red and Black wires that come with the screen and plugging them into the screens display board. The power and ground connections should be clearly labeled (don’t mix this up as it can destroy the display board and you will need to buy a whole new screen). Then route them to the connecting on the main circuit board in the upper left. Cut them to the appropriate length and then solder them to the board using a soldering iron. The power connection should be connected to the hole with the “+” next to it and the ground connection should be connected to the hole with the “-“ next to it.

## Step 6: Insert the joysticks and controller buttons

Install the joysticks making sure that the white connectors face towards the center of the device. They should fall into place with the tabs and the screw holes. Use the 2M x 4mm screws to attach the joysticks as shown in Figure 8. Do this for both sides.

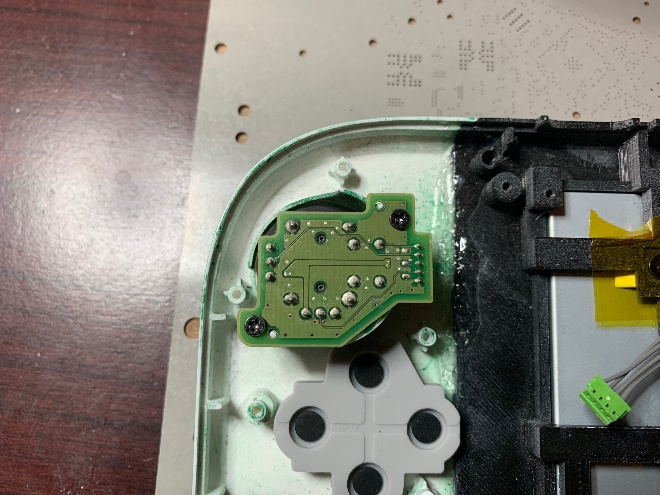
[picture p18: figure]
Joystick Installed

Figure 8: Joystick Installed

Add the face buttons into their corresponding places. They should align to the keying elements that were built into the case and the buttons. Then cover the buttons with the conductive rubber. If the rubber does not fit, then the rubber can be slightly cut to make sure it does. However, the black conductive part should not be tampered with as it would affect how well the buttons work. No cutting should be needed unless modifications were made to the case beyond what was offered in the repository. See Figures 9 and 10 for how this should look when installed. Do the same for the other side.

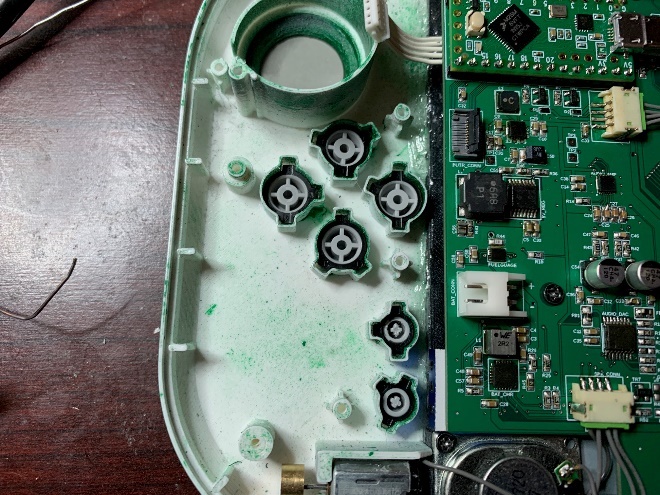
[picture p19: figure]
Buttons placed in case
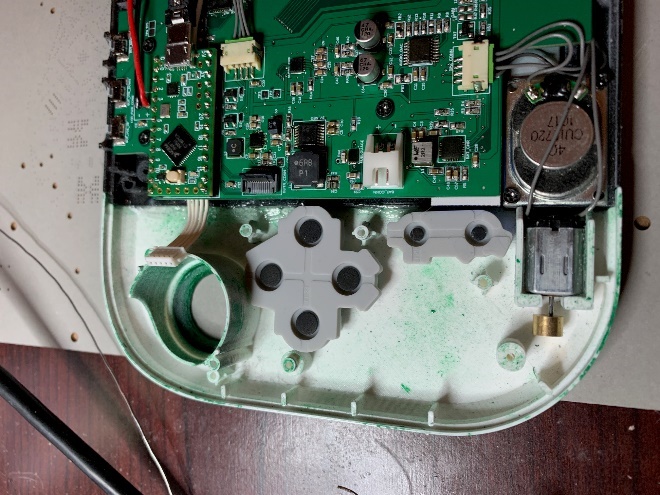
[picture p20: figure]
Conductive Rubber over buttons

Figure 9: Face Buttons Figure 10: Conductive Rubber over Buttons

Proceed by connecting the joystick wires from the main circuit board to the joysticks on both sides. They should go in the connectors without any twisting of the wires. If twisting is required, then re-examine the soldering order of the wires referring to step 1. See Figure 11 for the connected joystick wires.

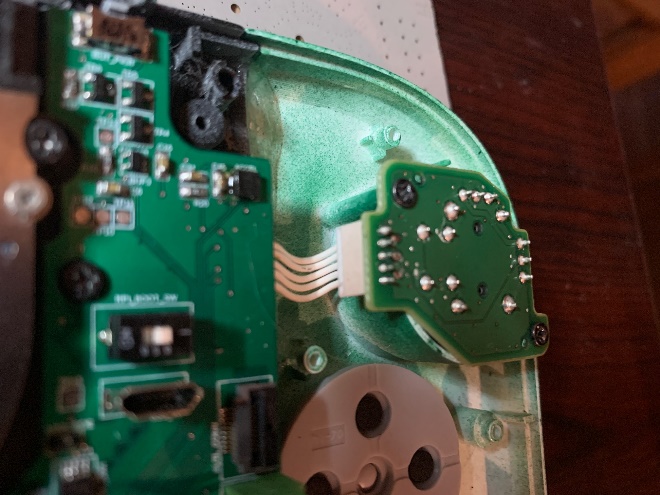
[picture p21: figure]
Joystick with Wires

Figure 11: Joysticks with Wires

After the buttons, conductive rubber, and joysticks have been installed then the white Wii U button sub-assemblies can be installed using 2M x 4mm screws as shown in Figure 12. You may have to remove the conductive rubber for the shoulder buttons to screw in the top screws. If so, then make sure to remember to put the conductive rubber back once the screws are in place.

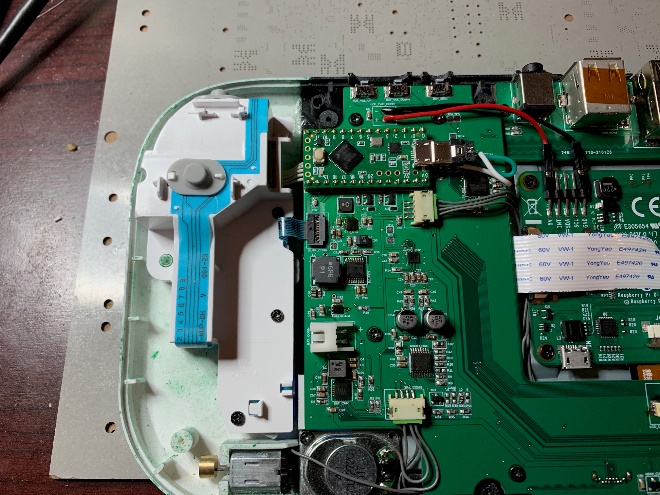
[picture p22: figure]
Wii U Button Sub-assemblies

Figure 12: Wii U Button Sub-Assemblies

Once the Wii U Button Sub-Assemblies are in place then connect the flexible connecting strip to the main circuit board on both sides. They should fit in without difficulty and the connector should clamp down on it preventing it from becoming lose. Make sure the flexible connecting strip is all the way into the connector to assure a good connection.

## Step 7: Install Heatsink, Fan, Optional Antenna, and Heat Pipe

First install the heatsinks and the copper piece as shown in Figure 13. It is recommended that the heat sinks be glued down using CA glue but heat resistant tape may also be used if that is available. Heat resistant tape must be used if using tape as the heatsink will get warm and the tape will lose its adhesion. After attaching the heatsinks, use heat transfer tape on top of them and then place a copper piece that fits the same size. I recommend measuring the heat sink area after they are attached to the case. In Figure 13 the white visible layer between the heatsinks and the copper is the heat transfer tape.

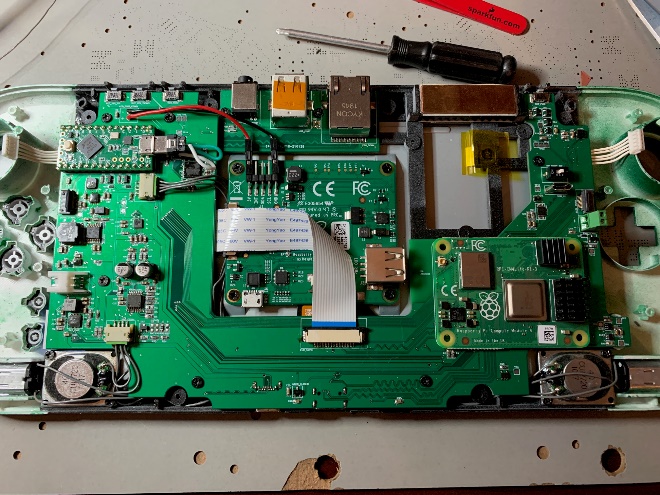
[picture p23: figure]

Figure 13: Heat Sinks and Copper Installed

After the heat sink/copper are installed then install the fan right below it, making sure that the screw holes line up correctly. See this in Figure 14. Once it is secure then place the red/black wires into the fan connector on the Main Circuit Board. The red wire should go into the side marked with “+” and the black wire goes into the side marked “-“. Make sure to tighten down the terminal heads once the wires are in place.

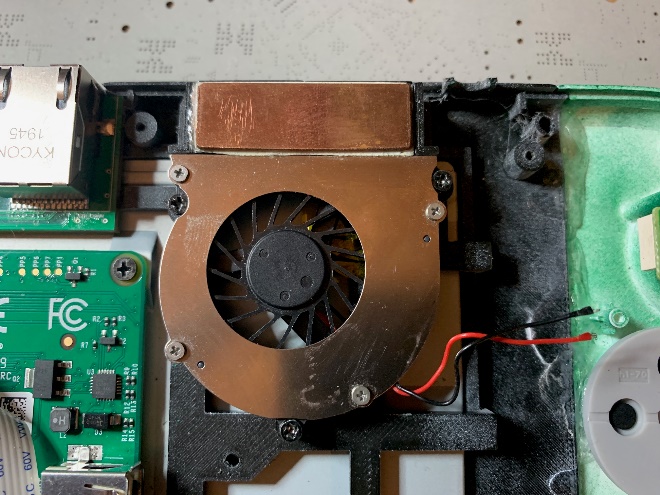
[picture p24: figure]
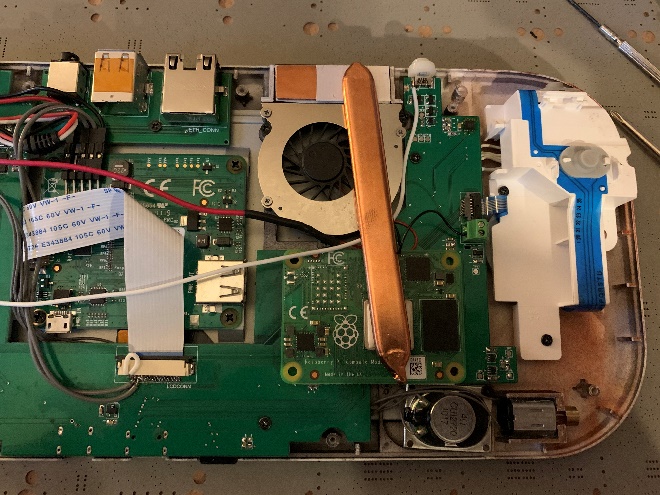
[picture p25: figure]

Figure 14: Fan Installation Figure 15: Heat Pipe

Now that the fan is installed the heat pipe may be placed over the raspberry pi CPU and the copper connecting the two for heat dissipation. Heat compounds like thermal paste or heat transfer tape may be used. I recommend heat transfer tape as it also secures the pipe in place so that it won’t come lose. See Figure 15 for a visual on where I placed the heat pipe. (Ignore the white wire as this picture came from a test unit I was building and had to modify the PCB)

Optionally the antenna can be installed at any point. While the heat pipe should not get hot enough to damage the wires of the antenna, I found that it is best to route the wire under the raspberry pi itself and under the heat pipe. See Figure 16 for how I installed and routed the antenna.

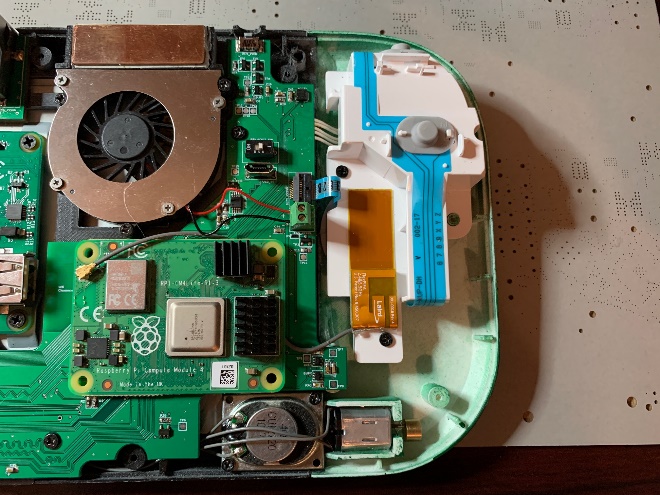
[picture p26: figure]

Figure 16: Antenna

## Step 8: Install the Battery

The batter most likely came with bare wires from Aliexpress. The first step is to attach the connecting wires from the Bill of Materials. These can either be directly soldered to the wires or for a cleaner approach you can peel back the tape and remove the thinners supplied on the battery and attach the new ones. Make sure that with either approach you take that you are correctly connecting the + and – terminal of the battery to the correct wire. However, if the latter approach is taken, be careful to not touch the any bare wires to any bare pads they should not be touching. Then use Kaplan tape to cover up the connection point again much like how it was before you peeled back the tape.

The battery can then be taped to the back of the case using any secure double-sided tape. Make sure that the double-sided tape you use is strong enough to hold it for extended use as you don’t want the batter to be coming lose while using it. Place the battery so that the connector can reach the battery plug provided on the main circuit board and so that it also doesn’t block the fan.

## Step 9: Install Power/Volume Buttons

Before closing the case put the top buttons caps over the buttons on the main circuit board. They should stick out the top of the device but also move freely when pressed. If any sanding is needed now would be the time to sand them down and test fit them for ease of use. The holes of the case may also be sanded if it is required.

## Step 10: Test and Final assembly

Finally, with everything assembled plug the battery into the board and see if the device turns on. It should automatically turn on when the battery is plugged in. If it does not, then make sure the battery has a charge. If you need to charge the battery, then that should be possible by plugging in the USB-C charging cord attached to the charging brick that is listed on the Bill of Materials. Once the battery is charged enough the device should just turn on. However, I would keep the device charging until the orange light on the first turns off to indicate that it is fully charged. The top LED on the front indicates that the device is on, while the bottom button indicates that it is charging.

From here attach the back cover using M2x6mm screws and start using the device. At the time of this writing, you might have to go through standard Raspberry Pi configuration to get the official screen working and the USB ports working. Otherwise, have FUN and ENJOY.

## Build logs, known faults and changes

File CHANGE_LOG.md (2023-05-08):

## Change Log

The change log of the Aegis 7" handheld.

Version Number Details:<br/>
x.0.0 - A new version number represents major changes to any and all aspects of the project. A new case and/or circuit board would be required.<br/>
0.x.0 - A new sub-version number represents changes to the circuit board and potentially software but no changes to the case that would require printing<br/>
0.0.x - A new stage represents only software changes where the previous version/sub-version will still work with the updated software. There will not be a separate folder for this update since it is only a software update.<br/>

### Version 1.0.0

Initial Release of the Aegis

### Version 1.0.1

Updated the controller.ino arduino code
1. Improved rumble feedback to better handle minimum and maximum vibrations
2. Changed the range of the joystick to better account for expected values received by the teensy
 
Updated the system_monitor.sh script
1. Changed the operation of the power button to be both a reset and power button. When pressed once it will reset, when held down for ~2sec it will power down.
2. Added correct use of the multi_switch.sh script

Updated startup.sh script to enable/disable the HDMI_MODE and HDMI_GROUP when detecting an HDMI connection<br/>
Updated the multi_switch.sh script to remove the extra endline characters that caused errors<br/>

### Version 1.1.0

Replaced the 1.8/3.3 V regulator on the circuit board with a 3.3V boost/buck regulator
Removed the Wifi/BT chip and associated components
Added a battery fuel gauge circuit
Updated the system_monitor.sh to use the new fuel gauge circuit for the battery indicator
Updated the startup.sh script so that it no longer selects HDMI groups and modes
Updated the setup.sh script to remove the HDMI 4k options as a choice when using HDMI
Removed the 1.8V to 3.3V convert for audio as GPIO_REF is now set to 3.3V
Removed the pull-up resistors on the LED's as they are not needed
Increased the screw hole wall thickness to prevent them from breaking as often
Increased the thickness of the inner structure to prevent flexing
Changed the teensy controller file to update inputs more frequently and to reduce rumble motor intensity

### Version 2.0.0

Updated the system_monitor.sh to a monitor application using C++ instead of Python and updated all associated code
Updated the startup.sh script so that it installs the new monitor application
Removed the bluetooth icon from the display as it is rarely used
Added assembly instructions
Increased the size of many supports and internal structure of the case to make it more rigid (The old 1.1 or 1.0 case will still work if you don't want to print the new one)

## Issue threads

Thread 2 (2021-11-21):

Part numbers/details

decafgeek, 2021-11-21:
Hi,
Just a request for some more detailed part numbers or descriptions, as prices have changed for several things.

- RPi CM4 - should indicate 'with wireless' (part number appears in URL, but would make things simpler
- Double-Sided, Thermal, Kaplan Tape - widths of these items would be useful to make sure the correct items are purchased
- Copper Plate - what dimensions and thickness are needed?

makermelissa, 2022-11-25:
I'm fairly sure the copper thickness is 0.3mm. It's the only one which the pre-discounted price matches the one in the BOM.

juckettd, 2023-01-17:
The copper thickness is actually 1mm, and it goes on top of the 4 heatsinks that all go together above the fan. Its purpose is to transfer the heat properly to all heat sinks from the heat pipe. This also levels out the overall height between the rasperry pi CM4 and the heatsinks so that the heat pipe doesn't touch the fan.

Also I had planned on updating the repo with better instructions on assembling the device but I never got around to it with the birth of my third child and work getting busier. However, I should have time soon to finish the instructions.

Musicislife6984, 2023-01-28:
I don't the TeensyUSB CONN 4 listed on the BOM. Could you give a part number, and how it is hooked up to the teensy please. I appreciate your great work!!

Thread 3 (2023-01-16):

Board not powering Up

deadca763, 2023-01-16:
Hello and first of all congratulations for this fabulous project!

I have a problem:
After soldering all the components on the PCB and after having assembled everything, the card refuses to start, when I press the POWER button nothing happens, I have a vBAT of 3.7v coming out but nothing more.
Nothing coming out from TR4 TR5 TR6 transistors

Any ideas?

I also saw on the Battery Charging IC that there is no connection on the vBAT and vBUS, is it normal?

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

Thanks in advance

juckettd, 2023-01-17:
It looks like to me that the board is missing some copper pours in those areas. I'd guess that it was a manufacturing area because those copper pours definitely exist in the CAM files. If you have enough skill with a soldering iron and have a fine enough tip you can solder wires to those same connections. The bottom one shouldn't be too difficult, but the top one might be harder as you have to connect to both of the pins to avoid running too much current through a single pin.

juckettd, 2023-01-17:
After looking at more of the picture there are more copper pours missing as well like the pour going up to L1 is missing

deadca763, 2023-01-17:
Indeed thanks, i've tried to solder these but things gets weird, like with the battery nothing else happens, and with the usb the rpi started to make some coil whine noises without pressing the power button, i'll re-check all solders and hope nothing bad happens !

juckettd, 2023-01-18:
Because there are copper pours missing with the battery charging circuit, it wouldn't surprise me if there are copper pours missing other places as well. That could definitely cause problems with power and ground connections to other items. Because I used copper pours to do better heat management with the circuits. So you might have a bigger problem and you should check your board with the supplied Eagle board files to see what is missing.

deadca763, 2023-01-18:
Okay thanks for the advice

deadca763, 2023-01-22:
The device is alive!
RPi is booting well and working, however it starts by itself when bat is plugged in, and can't stop it with the PWR Button, only resets it.

juckettd, 2023-01-23:
Yes that is correct. The circuitry will auto power up when it gets power from a USB source. You have to send it a signal from the I2C port of the raspberry pi to shut down power completely. The script I wrote does this to allow you to turn off the device. This is the monitor script that gets installed by the setup script. But I would like to point out that this script uses Dispmanx to do overlays on the screen and that is not compatible with the KMS driver. You have to use the FKMS video driver in your boot/config.txt file.

However, when it is charging it will be giving power to the rest of the system at the same time. But you can still shut down the raspberry pi even while it is charging through the script to save on some power. But the power from the device will still be there. It is like turning a Raspberry Pi off while leaving it plugged into the wall.

deadca763, 2023-01-24:
Yes however it happens even without usb power on it, the monitor script seems to work with overlays but when i execute the script's shutdown function it is still powered up (rpi shut down but power led still ON and all 3,3v 5v tensions still here)

Secondly, i tried charging the battery with usb power on it during all night and battery wasn't full (around 80% at 3,8v)

And lastly if you can tell me how to configure the teensy to be working with emulationstation, the buttons are recognized with the command tycmd and working fine, but when in emulationstation it is stuck at "Hold a button to configure gamepad"

Thanks for your help !

deadca763, 2023-01-25:
Here is a video of the problem when I push the power button and the controller buttons not responding in emulationstation, (it is working by monitoring with command "tycmd monitor")
https://user-images.githubusercontent.com/122821820/214675444-c1cb18a4-9dab-4a5c-907a-bc6735c6287c.mp4

juckettd, 2023-01-26:
How did you wire up the teensy? I'm looking through the instructions on the readme right now and something that I don't think I mentioned is you have to wire up the D+ and D- connections from the teensy to the board. There are four pads underneath the teensy and 4 pads in about the same spot on the board that I made. you don't need to connect the VBUS and GND connections, but you have to connect the D+ and D- connections. I just did it with some wire. With the teensy already soldered to the board it is a little tricket to do it but you can still get to both pads on both boards with a little work. I am assuming that this is the reason why your contrroller doesn't work.

As for the power button I'm not sure the monitor script is working, because if it is then there would be icons showing up in the upper right hand portion of the screen. Also the way the device reboots is a little concerning as it shouldn't turn white like that on the screen. That means that there is data corruption on the LCD lines going to the screen. This usually happens if there is a short somewhere that is causing the device to shut itself down due to the short and the power connection. With the script not running the button shouldn't do anything unless you hold it down for about 20 sec (where it does a hard reboot). You should check the trace with the button to to see if there is a bridged connection where power is getting connected to ground when the button is pressed.

deadca763, 2023-01-26:
I wired the 4 wires of the usb teensy, maybe i should remove the 5v and gnd as you said ?

And for the power problem i'll check for short circuit, i did

juckettd, 2023-01-26:
You shouldn't have to disconnect the VBUS and GND connections as they are just redundant. I doubt any power loops are causing this issue. Did you push the code to the teensy?

juckettd, 2023-01-26:
Also in the config.txt file there is a USB statement you need to put in there to enable the USB 2.0. The statement is "dtoverlay=dwc2,dr_mode=host". Make sure you also have this in your file. If the USB 2.0 still doesn't work then you should check the solder joints of the USB pins on the socket connector where the PI connects on the custom board. And check the solder joints on the USB hub circuit to make sure all of those pins are connected correctly.

deadca763, 2023-01-26:
I think it is working because the screen displays "1 gamepad detected" when d+ and d- of the teensy are connected, I'll re-check all what you said to be sure.

For the power problem I assume this is a difficult thing,
What is happening is when I push the button, QON, GPIO7 and GLOBAL_EN are falling to 0v, I think it is normal because shorted to ground with the transistors, but should I have Voltage at RUN_PG when rpi is started?
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

deadca763, 2023-01-26:
Also there is the end of the config.txt file
`[pi4]
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
deadca763, 2023-01-27:
Okay working now! it was the Xinput library missing on my arduino software x)

Problems still remaining :
-Hdmi plug not working
-Charging when powered off

juckettd, 2023-01-27:
That is great that the controller is working. I didn’t think to check the teensy libraries as I assumed it wouldn’t even install without the xinput library. When I update the install instructions I need to make sure that is specified.

The charging while on is unfortunately a side effect of the way it was designed. I modeled it after something like the iPhone where it is on when it charges. However, you can turn the raspberry pi off while it is charging once you plug the power cord in. But this still leaves power running to the pi. It is like doing a software shutdown without unplugging a regular PI 4. So it saves some power while charging but not everything.

The HDMI not working is probably due to some bridged or unsoldered pins on the HDMI connector. Those pins are very close together and I found I had to clean them up after I put it together using my reflow station. A fine soldering tip comes in a handy here. If that isn’t the case for you then I’d also check the pins on the PI socket connected to see if something similar is happening.

deadca763, 2023-01-27:
Okay no problem for the charge
I'll re-check all solders on the hdmi port
I tried the device with a little game and working fine! but how the fan is working? Because it stays off, do I need to put the thermister on the rpi cpu or somewhere?

juckettd, 2023-01-27:
Just to give you info on the charging thing, I realized after I used the device for a while that the way the power and charging works isn't that great. I am changing it for a future design but that will be for an Aegis 2 device and not this one unfortunately. However, I do have a update that I will be pushing up soon for this that will address some software issues where it lags a bit in some games with the screen overlay. I also made some really minor PCB changes that improved some power routing issues to the SD card. But that only shows up when the power gets below 3.0V from the battery. I didn't notice it until recently because I never let the battery get that low.

juckettd, 2023-01-27:
Also for the fan. it is setup in the monitor script to turn on when the Raspberry PI reaches 50 degress C. So if you play a intense game you will hear it come on from time to time. But otherwise it will stay off. And when it does come on it will only come on for as long as it takes to drop the temp back down below 50 and then another minute after that to prevent it from turning back on immediately again.

deadca763, 2023-01-27:
Can't wait to see the ver. 2 finished!
For the fan, the RFB4505 reference no longer available, I replaced it with a 30x30x4mm square fan, here :[https://fr.aliexpress.com/item/1005003167391047.html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](url)
Still waiting to receive it i replaced temporarily with a little dc fan to see if working but nope, I checked the Voltages and there is around 3v output from the + and - pins of the connector of the board, Don't know if it's normal but seems not.

juckettd, 2023-01-27:
The voltage to the fan is 3.3V. I run it lower then 5V because at 5V the original fan was just too loud and had a high pitched squeal to it. I tested it out a lot to make sure it can handle 3.3V to run at a lower speed. But not all fans can accomodate a lower voltage then it was originally designed for.

deadca763, 2023-01-28:
Yesterday a weird thing happened, the battery was low and the auto stop function didn't work, Bat came below 3v (2.6v) and device started to disfunction in loop, like screen blanking, restart by itself and unability to shutdown, I had to disconnect the battery to stop it and remove raspberry to charge the battery without starting the device. Don't know what happened :/

A little question, can I run the device with 2 systems? like the retropie on the eMMC of the Pi and another system on the SD Card?

Musicislife6984, 2023-02-13:
> The device is alive!
>
> RPi is booting well and working, however it starts by itself when bat is plugged in, and can't stop it with the PWR Button, only resets it.

Did you find any other missing pours? I just got my PCB from JLCPCB and it is missing those as well. I appreciate any help as I am getting ready to start my build.

deadca763, 2023-02-14:
All missing pours concern the bat_chr ic, 5v_reg and the audio_dac, on the board file you can see all of it by the dotted lines, some screens here to show you.

PS: you also need to check where the 2nd little board connects to the main board, 5v alim is missing too

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

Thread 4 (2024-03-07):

Mention current status of Version 2.0 in Readme

ctsrc, 2024-03-07:
The readme mentions that the design is complete, but it is hard to know at a glance if that applies to only Version 1.0 or Version 2.0, or both.

A short section stating the status of both versions, and recommending which one you should use and what is the difference between these two versions would be highly appreciated

juckettd, 2024-03-28:
Version 2.0 is the one that should be used if you want to build a new one. However, I kept the 1.0 version in case anybody still needed those files. As for the difference between the two you can look at the Change_Log.MD file to see what the differences are.

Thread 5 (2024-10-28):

Suggested substitutions for obsolete pcb components

zcspencer, 2024-10-28:
Hello! Love the project!
As I was assembling my digikey shopping cart, I noticed two components that are marked in Digikey as obsolete.
Looking for substitutions, I could not find any drop in replacements for the following parts:
- [F980J107MMAAXE](https://www.digikey.com/en/products/detail/kyocera-avx/F980J107MMAAXE/5957626) (Tantalum Capacitor),
- [MMA8451QR1](https://www.digikey.com/en/products/detail/nxp-usa-inc/MMA8451QR1/2508916) (Accelerometer)

Curious if there are any recommendations, substitutions, or workarounds?

Thank you!

weirdgyn, 2024-10-28:
I think caps will not be a problem... NXP suggest FXLS8971CF or FXLS8974CF as replacement for MMA8451QR1.. they're not pin-2-pin compatibile.

zcspencer, 2024-10-28:
Thank you for your response! So are you saying that I can safely omit the capacitor?

weirdgyn, 2024-10-29:
Nope.. you have to find a replacement with the same specifications:

type: tantalum capacitor (molded)
package size: 0603
voltage rating: 6.3V
capacity: 100uF (100 micro faradays)
tollerance: 20%

but it is an easier task than replacing an IMU.

So far I cannot find anything identical but I just looked on global providers non on specific productors catalogs.

This's quite the same: TLJP107M006R5400
it's a little larger being 0805 instead 0603... so you will have to edit the board to fit the new cap.

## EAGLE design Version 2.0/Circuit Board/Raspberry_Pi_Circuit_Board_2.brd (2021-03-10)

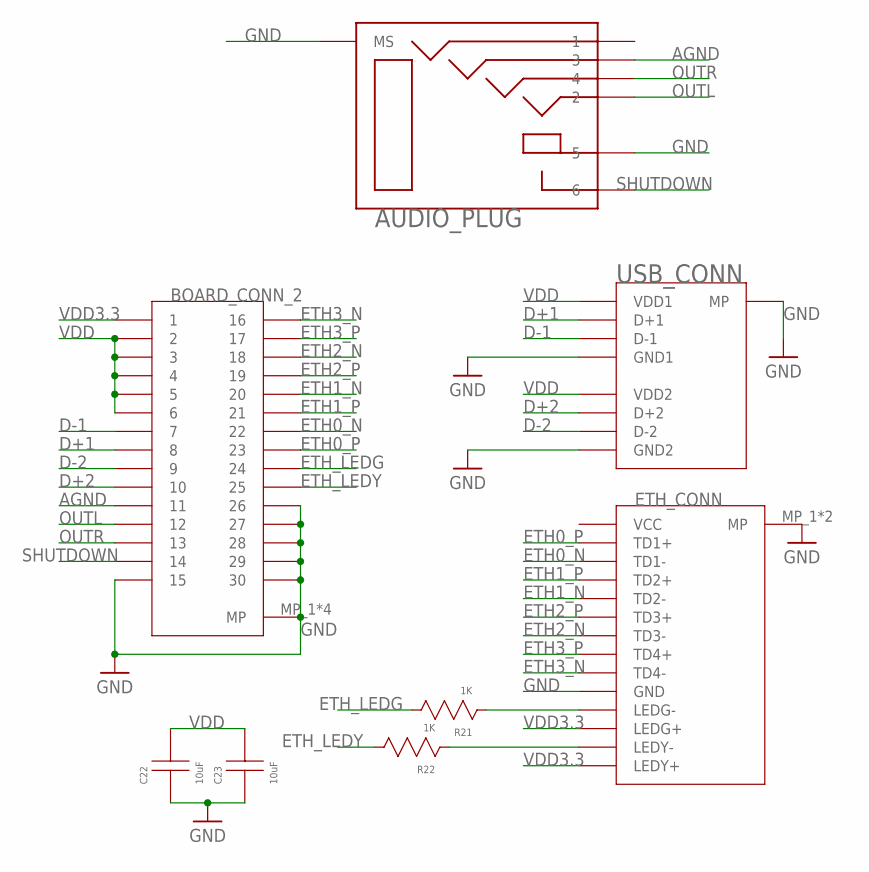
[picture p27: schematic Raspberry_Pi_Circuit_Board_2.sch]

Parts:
AUDIO_PLUG: AUDIOPLUG-ASJ-192-Y-TR
BOARD_CONN_2: MEZZANINE-AXT530124
C22, C23: 10uF; CAP-603
ETH_CONN: ETH-GLPLX-SMT-188S7-QQ-Y/G
R21, R22: 1K; RES-603
USB_CONN: USB-614108646521

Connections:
AGND: AUDIO_PLUG.3, BOARD_CONN_2.11
D+1: BOARD_CONN_2.8, USB_CONN.D+1
D+2: BOARD_CONN_2.10, USB_CONN.D+2
D-1: BOARD_CONN_2.7, USB_CONN.D-1
D-2: BOARD_CONN_2.9, USB_CONN.D-2
ETH0_N: BOARD_CONN_2.22, ETH_CONN.TD1-
ETH0_P: BOARD_CONN_2.23, ETH_CONN.TD1+
ETH1_N: BOARD_CONN_2.20, ETH_CONN.TD2-
ETH1_P: BOARD_CONN_2.21, ETH_CONN.TD2+
ETH2_N: BOARD_CONN_2.18, ETH_CONN.TD3-
ETH2_P: BOARD_CONN_2.19, ETH_CONN.TD3+
ETH3_N: BOARD_CONN_2.16, ETH_CONN.TD4-
ETH3_P: BOARD_CONN_2.17, ETH_CONN.TD4+
ETH_LEDG: BOARD_CONN_2.24, R21.C
ETH_LEDY: BOARD_CONN_2.25, R22.C
GND: AUDIO_PLUG.5, AUDIO_PLUG.MS1 (MS), AUDIO_PLUG.MS2 (MS), BOARD_CONN_2.15, BOARD_CONN_2.26, BOARD_CONN_2.27, BOARD_CONN_2.28, BOARD_CONN_2.29, BOARD_CONN_2.30, BOARD_CONN_2.MP_1 (MP), BOARD_CONN_2.MP_2 (MP), BOARD_CONN_2.MP_3 (MP), BOARD_CONN_2.MP_4 (MP), C22.A, C23.A, ETH_CONN.GND, ETH_CONN.MP_1 (MP), ETH_CONN.MP_2 (MP), USB_CONN.GND1, USB_CONN.GND2, USB_CONN.MP_1 (MP), USB_CONN.MP_2 (MP), USB_CONN.MP_3 (MP), USB_CONN.MP_4 (MP)
unnamed: ETH_CONN.LEDG-, R21.A
unnamed: ETH_CONN.LEDY-, R22.A
OUTL: AUDIO_PLUG.2, BOARD_CONN_2.12
OUTR: AUDIO_PLUG.4, BOARD_CONN_2.13
SHUTDOWN: AUDIO_PLUG.6, BOARD_CONN_2.14
VDD: BOARD_CONN_2.2, BOARD_CONN_2.3, BOARD_CONN_2.4, BOARD_CONN_2.5, BOARD_CONN_2.6, C22.C, C23.C, USB_CONN.VDD1, USB_CONN.VDD2
VDD3.3: BOARD_CONN_2.1, ETH_CONN.LEDG+, ETH_CONN.LEDY+

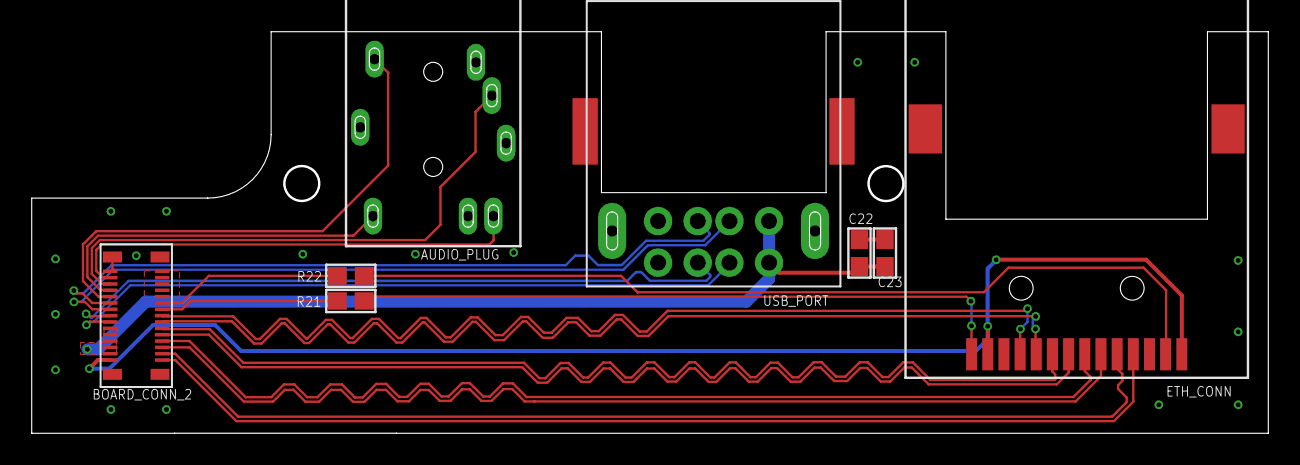
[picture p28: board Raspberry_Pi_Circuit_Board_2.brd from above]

Board: 2 copper layers, 78.0 x 25.3 mm, 8 parts (0 on the bottom side), 23 nets.

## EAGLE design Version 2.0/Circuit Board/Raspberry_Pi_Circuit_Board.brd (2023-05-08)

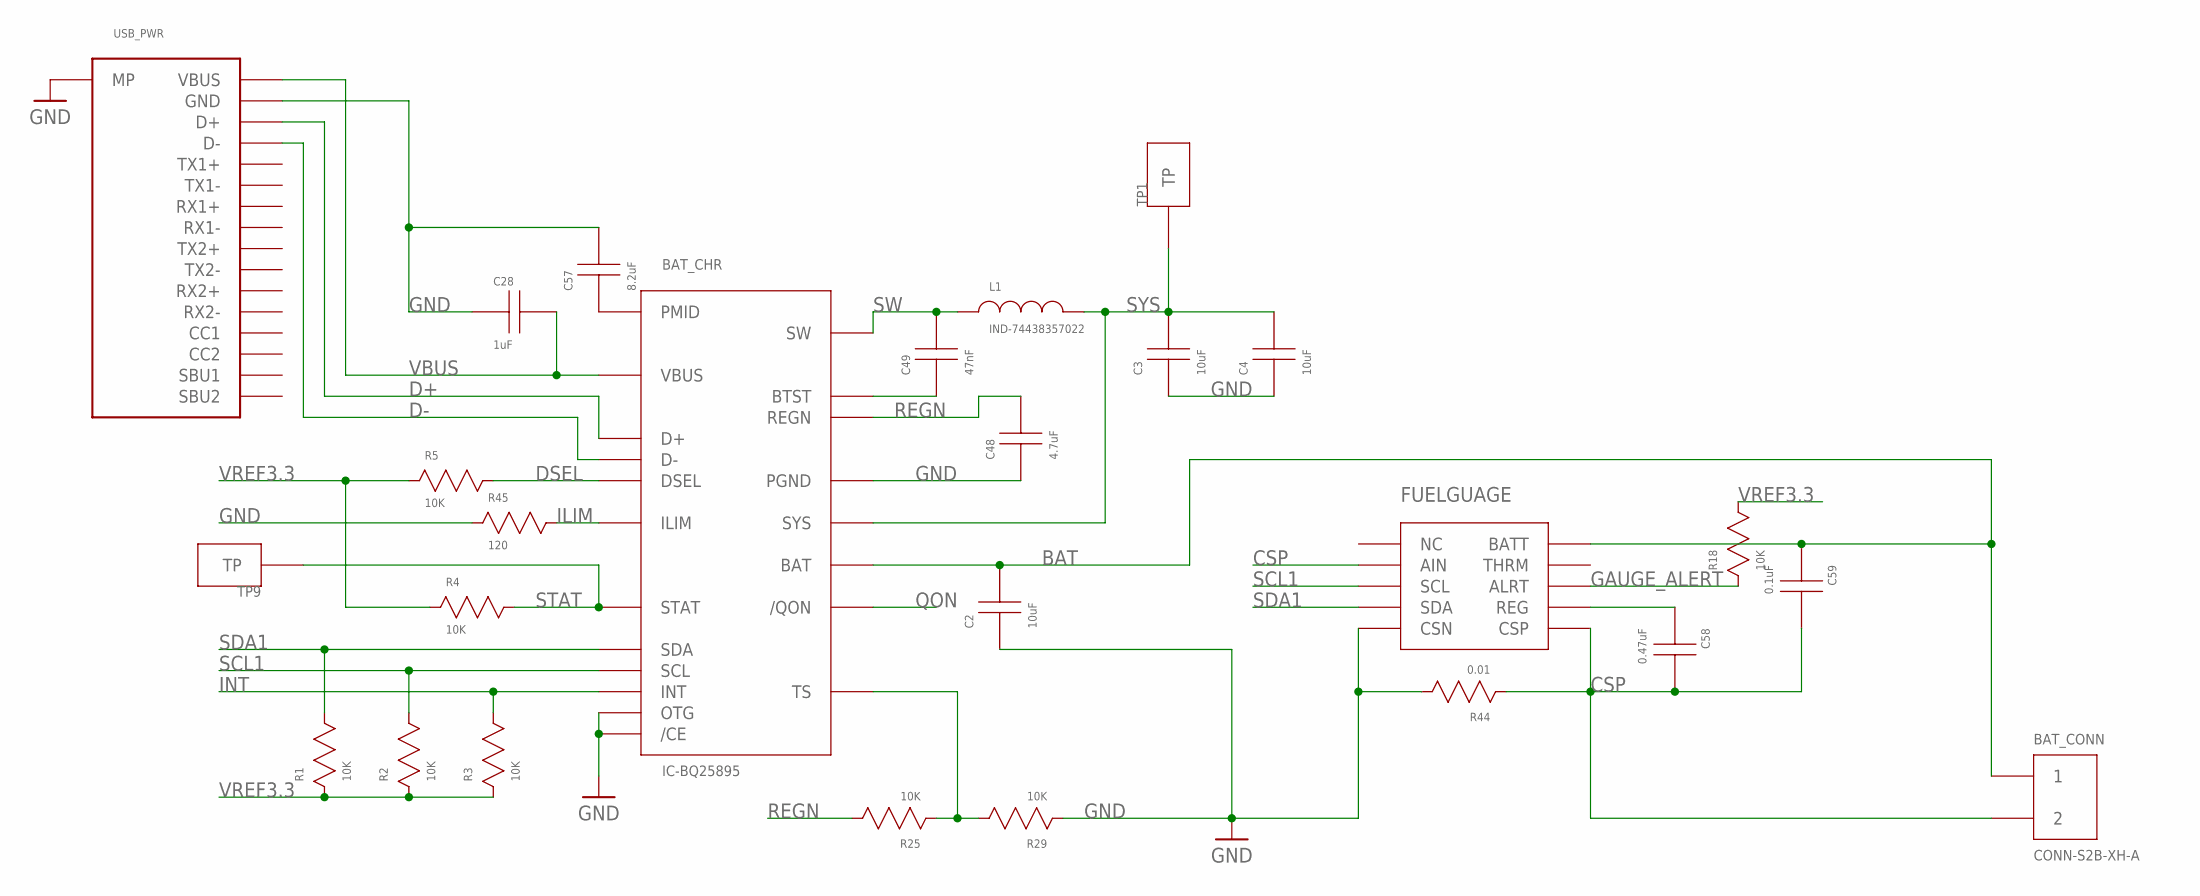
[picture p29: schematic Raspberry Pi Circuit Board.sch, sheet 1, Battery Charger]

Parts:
BAT_CHR: IC-BQ25895
BAT_CONN: CONN-S2B-XH-A
C2, C3, C4: 10uF; CAP-603
C28: 1uF; CAP-603
C48: 4.7uF; CAP-603
C49: 47nF; CAP-603
C57: 8.2uF; CAP-603
C58: 0.47uF; CAP-603
C59: 0.1uF; CAP-603
FUELGUAGE: IC-MAX17055
L1: IND-74438357022
R1, R2, R3, R4, R5, R18, R25, R29: 10K; RES-603
R44: 0.01; RES-603
R45: 120; RES-603
TP1, TP9: TESTPOINT
USB_PWR: USBC-USB-C31-S-RA-CS1D-BK-T/R

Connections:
BAT: BAT_CHR.BAT1 (BAT), BAT_CHR.BAT2 (BAT), BAT_CONN.1, C2.C, C59.A, FUELGUAGE.BATT; also elsewhere on the board
CSP: BAT_CONN.2, C58.C, C59.C, FUELGUAGE.AIN, FUELGUAGE.CSP, FUELGUAGE.EP (CSP), R44.A
D+: BAT_CHR.D+, USB_PWR.D+, USB_PWR.D+_2 (D+)
D-: BAT_CHR.D-, USB_PWR.D-, USB_PWR.D-_2 (D-)
DSEL: BAT_CHR.DSEL, R5.C
GAUGE_ALERT: FUELGUAGE.ALRT, R18.A; also elsewhere on the board
GND: BAT_CHR./CE, BAT_CHR.OTG, BAT_CHR.PGND1 (PGND), BAT_CHR.PGND2 (PGND), BAT_CHR.PWRPAD (PGND), C2.A, C3.A, C4.A, C28.A, C48.A, C57.C, FUELGUAGE.CSN, R29.A, R44.C, R45.A, USB_PWR.GND_1 (GND), USB_PWR.GND_2 (GND), USB_PWR.GND_3 (GND), USB_PWR.GND_4 (GND), USB_PWR.MP_1 (MP), USB_PWR.MP_2 (MP), USB_PWR.MP_3 (MP), USB_PWR.MP_4 (MP); also elsewhere on the board
ILIM: BAT_CHR.ILIM, R45.C
INT: BAT_CHR.INT, R3.C; also elsewhere on the board
unnamed: BAT_CHR.BTST, C49.A
unnamed: BAT_CHR.TS, R25.A, R29.C
unnamed: BAT_CHR.PMID, C57.A
unnamed: C58.A, FUELGUAGE.REG
QON: BAT_CHR./QON; also elsewhere on the board
REGN: BAT_CHR.REGN, C48.C, R25.C
SCL1: BAT_CHR.SCL, FUELGUAGE.SCL, R2.C; also elsewhere on the board
SDA1: BAT_CHR.SDA, FUELGUAGE.SDA, R1.C; also elsewhere on the board
STAT: BAT_CHR.STAT, R4.C, TP9.TP; also elsewhere on the board
SW: BAT_CHR.SW1 (SW), BAT_CHR.SW2 (SW), C49.C, L1.A
SYS: BAT_CHR.SYS1 (SYS), BAT_CHR.SYS2 (SYS), C3.C, C4.C, L1.C, TP1.TP; also elsewhere on the board
VBUS: BAT_CHR.VBUS, C28.C, USB_PWR.VBUS_1 (VBUS), USB_PWR.VBUS_2 (VBUS), USB_PWR.VBUS_3 (VBUS), USB_PWR.VBUS_4 (VBUS)
VREF3.3: R1.A, R2.A, R3.A, R4.A, R5.A, R18.C; also elsewhere on the board

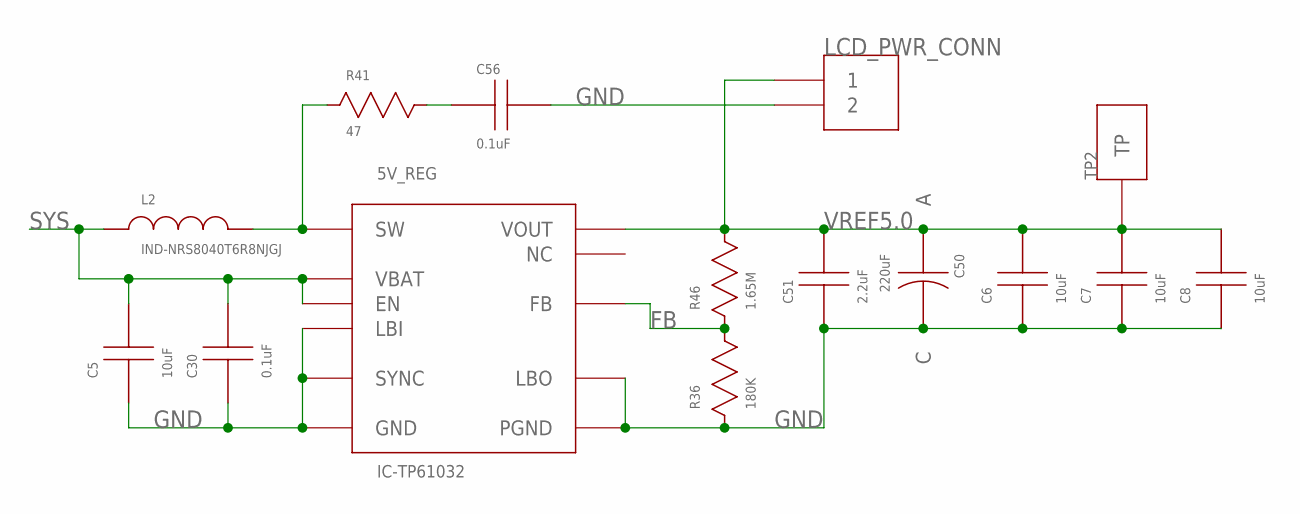
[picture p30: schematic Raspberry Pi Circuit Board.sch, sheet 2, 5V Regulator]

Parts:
5V_REG: IC-TP61032; IC-TPS61032
C5, C6, C7, C8: 10uF; CAP-603
C30, C56: 0.1uF; CAP-603
C50: 220uF; CAP-TAN-1411
C51: 2.2uF; CAP-603
L2: IND-NRS8040T6R8NJGJ
LCD_PWR_CONN: CONN-282834-2
R36: 180K; RES-603
R41: 47; RES-603
R46: 1.65M; RES-603
TP2: TESTPOINT

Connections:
FB: 5V_REG.FB, R36.C, R46.A
GND: 5V_REG.GND, 5V_REG.LBI, 5V_REG.LBO, 5V_REG.PGND1 (PGND), 5V_REG.PGND2 (PGND), 5V_REG.PGND3 (PGND), 5V_REG.PWRPAD (PGND), 5V_REG.SYNC, C5.A, C6.A, C7.A, C8.A, C30.A, C50.C, C51.A, C56.C, LCD_PWR_CONN.2, R36.A; also elsewhere on the board
unnamed: C56.A, R41.C
SNUB: 5V_REG.SW1 (SW), 5V_REG.SW2 (SW), L2.C, R41.A
SYS: 5V_REG.EN, 5V_REG.VBAT, C5.C, C30.C, L2.A; also elsewhere on the board
VREF5.0: 5V_REG.VOUT1 (VOUT), 5V_REG.VOUT2 (VOUT), 5V_REG.VOUT3 (VOUT), C6.C, C7.C, C8.C, C50.A, C51.C, LCD_PWR_CONN.1, R46.C, TP2.TP; also elsewhere on the board

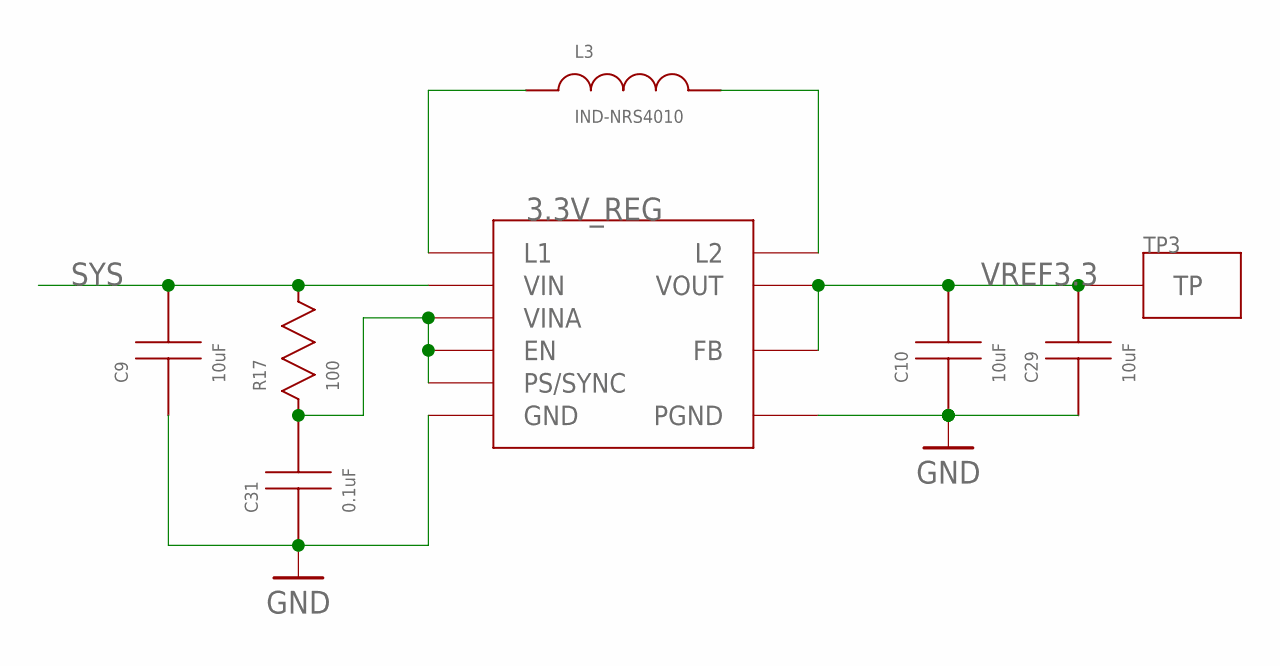
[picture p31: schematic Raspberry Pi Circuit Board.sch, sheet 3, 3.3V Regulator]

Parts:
3.3V_REG: IC-TPS63001DRCR
C9, C10, C29: 10uF; CAP-603
C31: 0.1uF; CAP-603
L3: IND-NRS4010
R17: 100; RES-603
TP3: TESTPOINT

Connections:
GND: 3.3V_REG.GND, 3.3V_REG.PGND, 3.3V_REG.PGND_1 (PGND), 3.3V_REG.PGND_2 (PGND), 3.3V_REG.PGND_3 (PGND), 3.3V_REG.PGND_4 (PGND), 3.3V_REG.PGND_5 (PGND), C9.A, C10.A, C29.A, C31.A; also elsewhere on the board
unnamed: 3.3V_REG.EN, 3.3V_REG.PS/SYNC, 3.3V_REG.VINA, C31.C, R17.A
unnamed: 3.3V_REG.L1, L3.A
unnamed: 3.3V_REG.L2, L3.C
SYS: 3.3V_REG.VIN, C9.C, R17.C; also elsewhere on the board
VREF3.3: 3.3V_REG.FB, 3.3V_REG.VOUT, C10.C, C29.C, TP3.TP; also elsewhere on the board

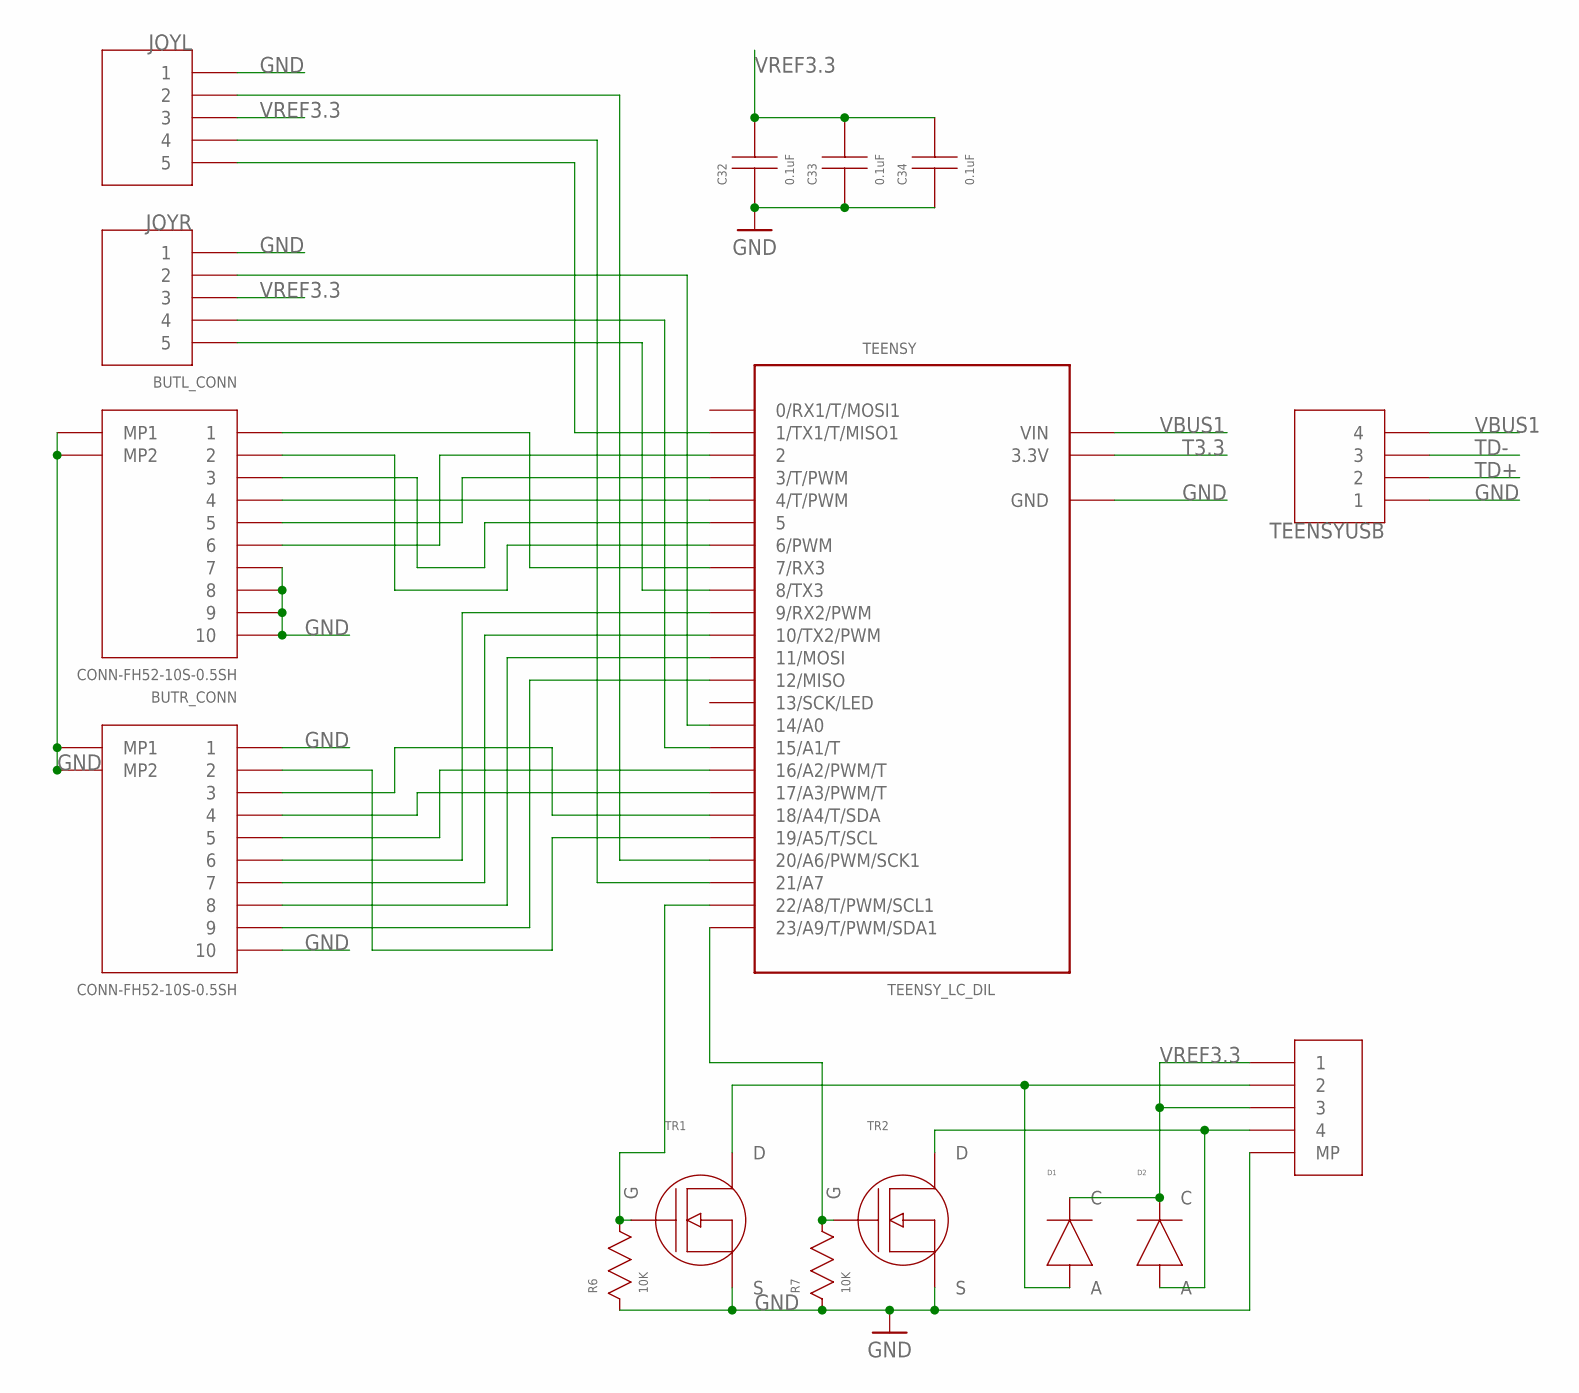
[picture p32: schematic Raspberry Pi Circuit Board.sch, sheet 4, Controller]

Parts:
BUTL_CONN: CONN-FH52-10S-0.5SH
BUTR_CONN: CONN-FH52-10S-0.5SH
C32, C33, C34: 0.1uF; CAP-603
D1, D2: DIODE-X3-WLB1608-2
JOYL: CONN_5PIN
JOYR: CONN_5PIN
MOT_CONN: CONN-VS4B-ZR-SM4A-TF
R6, R7: 10K; RES-603
TEENSY: TEENSY_LC_DIL; TEENSY_3.0-3.2&LC_DIL
TEENSYUSB: CONN_4PIN
TR1, TR2: TRAN-DMG2302UKQ

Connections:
GND: BUTL_CONN.7, BUTL_CONN.8, BUTL_CONN.9, BUTL_CONN.10, BUTL_CONN.MP1, BUTL_CONN.MP2, BUTR_CONN.1, BUTR_CONN.10, BUTR_CONN.MP1, BUTR_CONN.MP2, C32.A, C33.A, C34.A, JOYL.1, JOYR.1, MOT_CONN.MP_1 (MP), MOT_CONN.MP_2 (MP), R6.A, R7.A, TEENSY.AGND (GND), TEENSY.GND, TEENSYUSB.1, TR1.S, TR2.S; also elsewhere on the board
unnamed: JOYR.2, TEENSY.14/A0
unnamed: JOYR.4, TEENSY.15/A1 (15/A1/T)
unnamed: R6.C, TEENSY.22/A8 (22/A8/T/PWM/SCL1), TR1.G
unnamed: R7.C, TEENSY.23/A9 (23/A9/T/PWM/SDA1), TR2.G
unnamed: BUTR_CONN.8, TEENSY.11 (11/MOSI)
unnamed: D2.A, MOT_CONN.4, TR2.D
unnamed: D1.A, MOT_CONN.2, TR1.D
unnamed: BUTR_CONN.9, TEENSY.12 (12/MISO)
unnamed: BUTR_CONN.7, TEENSY.10 (10/TX2/PWM)
unnamed: BUTR_CONN.6, TEENSY.9 (9/RX2/PWM)
unnamed: JOYR.5, TEENSY.8 (8/TX3)
unnamed: BUTR_CONN.5, TEENSY.16/A2 (16/A2/PWM/T)
unnamed: BUTR_CONN.4, TEENSY.17/A3 (17/A3/PWM/T)
unnamed: BUTR_CONN.3, TEENSY.18/A4 (18/A4/T/SDA)
unnamed: BUTR_CONN.2, TEENSY.19/A5 (19/A5/T/SCL)
unnamed: JOYL.2, TEENSY.20/A6 (20/A6/PWM/SCK1)
unnamed: JOYL.4, TEENSY.21/A7
unnamed: JOYL.5, TEENSY.1 (1/TX1/T/MISO1)
unnamed: BUTL_CONN.6, TEENSY.2
unnamed: BUTL_CONN.5, TEENSY.3 (3/T/PWM)
unnamed: BUTL_CONN.4, TEENSY.4 (4/T/PWM)
unnamed: BUTL_CONN.3, TEENSY.5
unnamed: BUTL_CONN.2, TEENSY.6 (6/PWM)
unnamed: BUTL_CONN.1, TEENSY.7 (7/RX3)
T3.3: TEENSY.3.3V
TD+: TEENSYUSB.2; also elsewhere on the board
TD-: TEENSYUSB.3; also elsewhere on the board
VBUS1: TEENSY.VIN, TEENSYUSB.4; also elsewhere on the board
VREF3.3: C32.C, C33.C, C34.C, D1.C, D2.C, JOYL.3, JOYR.3, MOT_CONN.1, MOT_CONN.3; also elsewhere on the board

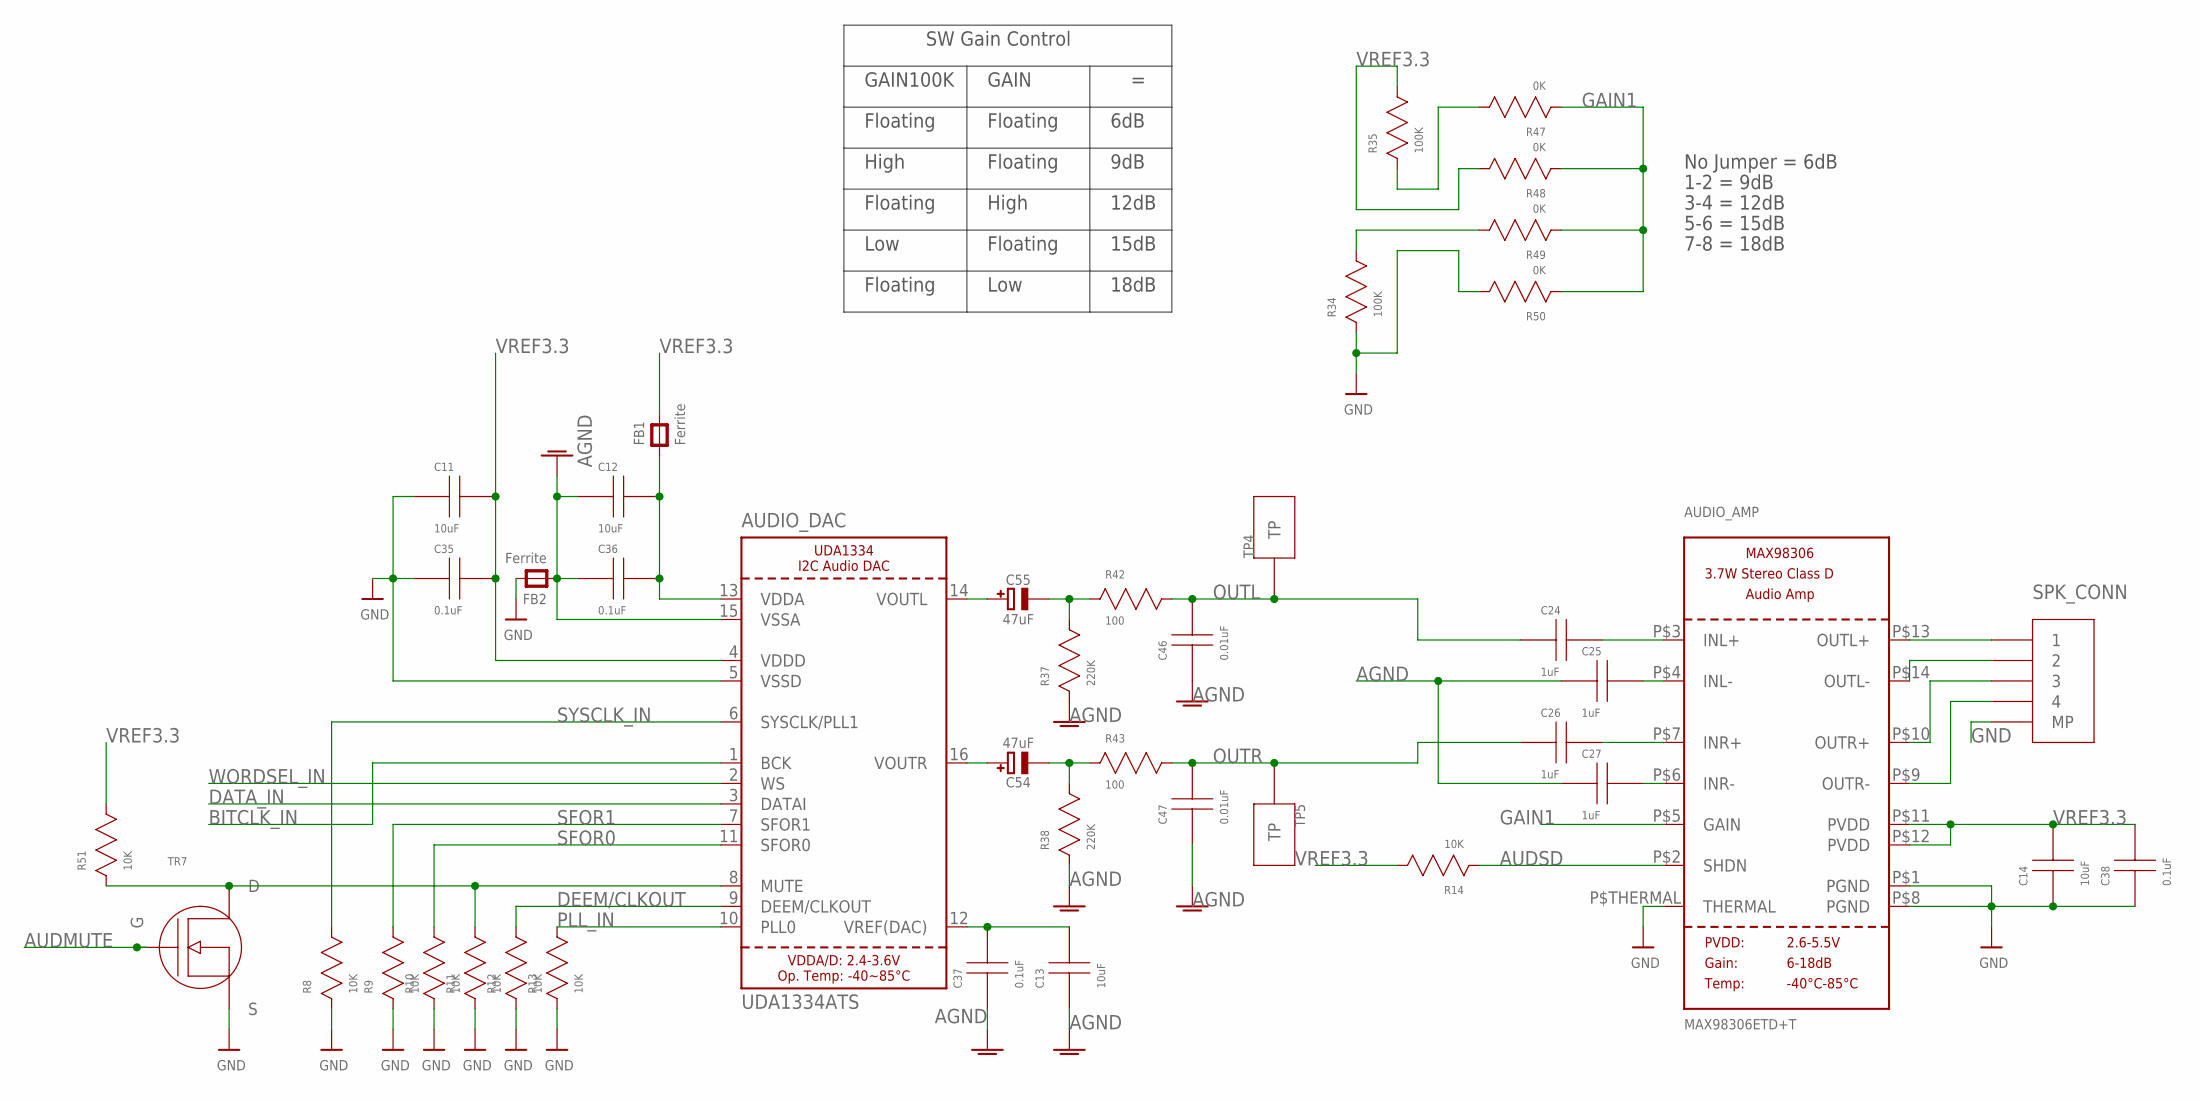
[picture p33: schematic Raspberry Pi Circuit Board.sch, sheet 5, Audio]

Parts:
AUDIO_AMP: MAX98306ETD+T; TDFN14_3X3MM
AUDIO_DAC: UDA1334ATS; SSOP16_4.4MM
C11, C12, C13, C14: 10uF; CAP-603
C24, C25, C26, C27: 1uF; CAP-603
C35, C36, C37, C38: 0.1uF; CAP-603
C46, C47: 0.01uF; CAP-603
C54, C55: 47uF; PANASONIC_C
FB1, FB2: Ferrite; 0805@1
R8, R9, R10, R11, R12, R13, R14, R51: 10K; RES-603
R34, R35: 100K; RES-603
R37, R38: 220K; RES-603
R42, R43: 100; RES-603
R47, R48, R49, R50: 0K; RES-603
SPK_CONN: CONN-VS4B-ZR-SM4A-TF
TP4, TP5: TESTPOINT
TR7: TRAN-DMG2302UKQ

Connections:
AGND: AUDIO_DAC.15 (VSSA), C12.A, C13.A, C25.A, C27.A, C36.A, C37.A, C46.A, C47.A, FB2.1, R37.A, R38.A; also elsewhere on the board
AUDMUTE: TR7.G; also elsewhere on the board
AUDSD: AUDIO_AMP.P$2 (SHDN), R14.A; also elsewhere on the board
BITCLK_IN: AUDIO_DAC.1 (BCK); also elsewhere on the board
DATA_IN: AUDIO_DAC.3 (DATAI); also elsewhere on the board
DEEM/CLKOUT: AUDIO_DAC.9 (DEEM/CLKOUT), R12.C
GAIN1: AUDIO_AMP.P$5 (GAIN), R47.A, R48.A, R49.A, R50.A
GND: AUDIO_AMP.P$1 (PGND), AUDIO_AMP.P$8 (PGND), AUDIO_AMP.P$THERMAL (THERMAL), AUDIO_DAC.5 (VSSD), C11.A, C14.A, C35.A, C38.A, FB2.2, R8.A, R9.A, R10.A, R11.A, R12.A, R13.A, R34.A, R50.C, SPK_CONN.MP_1 (MP), SPK_CONN.MP_2 (MP), TR7.S; also elsewhere on the board
unnamed: AUDIO_DAC.13 (VDDA), C12.C, C36.C, FB1.1
unnamed: C54.-, R38.C, R43.A
unnamed: C55.-, R37.C, R42.A
unnamed: AUDIO_DAC.8 (MUTE), R11.C, R51.A, TR7.D
unnamed: AUDIO_DAC.12 (VREF(DAC)), C13.C, C37.C
unnamed: AUDIO_DAC.16 (VOUTR), C54.+
unnamed: AUDIO_DAC.14 (VOUTL), C55.+
unnamed: R35.A, R47.C
unnamed: R34.C, R49.C
unnamed: AUDIO_AMP.P$3 (INL+), C24.C
unnamed: AUDIO_AMP.P$4 (INL-), C25.C
unnamed: AUDIO_AMP.P$7 (INR+), C26.C
unnamed: AUDIO_AMP.P$6 (INR-), C27.C
unnamed: AUDIO_AMP.P$13 (OUTL+), SPK_CONN.1
unnamed: AUDIO_AMP.P$14 (OUTL-), SPK_CONN.2
unnamed: AUDIO_AMP.P$10 (OUTR+), SPK_CONN.3
unnamed: AUDIO_AMP.P$9 (OUTR-), SPK_CONN.4
OUTL: C24.A, C46.C, R42.C, TP4.TP; also elsewhere on the board
OUTR: C26.A, C47.C, R43.C, TP5.TP; also elsewhere on the board
PLL_IN: AUDIO_DAC.10 (PLL0), R13.C
SFOR0: AUDIO_DAC.11 (SFOR0), R10.C
SFOR1: AUDIO_DAC.7 (SFOR1), R9.C
SYSCLK_IN: AUDIO_DAC.6 (SYSCLK/PLL1), R8.C
VREF3.3: AUDIO_AMP.P$11 (PVDD), AUDIO_AMP.P$12 (PVDD), AUDIO_DAC.4 (VDDD), C11.C, C14.C, C35.C, C38.C, FB1.2, R14.C, R35.C, R48.C, R51.C; also elsewhere on the board
WORDSEL_IN: AUDIO_DAC.2 (WS); also elsewhere on the board

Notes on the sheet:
GAIN100K
GAIN
Floating
6dB
High
9dB
12dB
Low
15dB
18dB
SW Gain Control
No Jumper = 6dB
1-2 = 9dB
3-4 = 12dB
5-6 = 15dB
7-8 = 18dB

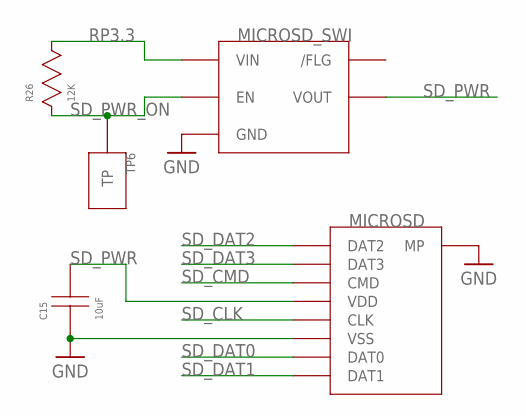
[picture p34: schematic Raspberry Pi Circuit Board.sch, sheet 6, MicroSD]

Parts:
C15: 10uF; CAP-603
MICROSD: MICROSD-5033981892_SD
MICROSD_SWI: IC-RT9742
R26: 12K; RES-603
TP6: TESTPOINT

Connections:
GND: C15.A, MICROSD.DL (MP), MICROSD.DS (MP), MICROSD.MP_1 (MP), MICROSD.MP_2 (MP), MICROSD.MP_3 (MP), MICROSD.MP_4 (MP), MICROSD.VSS, MICROSD_SWI.GND; also elsewhere on the board
RP3.3: MICROSD_SWI.VIN, R26.C; also elsewhere on the board
SD_CLK: MICROSD.CLK; also elsewhere on the board
SD_CMD: MICROSD.CMD; also elsewhere on the board
SD_DAT0: MICROSD.DAT0; also elsewhere on the board
SD_DAT1: MICROSD.DAT1; also elsewhere on the board
SD_DAT2: MICROSD.DAT2; also elsewhere on the board
SD_DAT3: MICROSD.DAT3; also elsewhere on the board
SD_PWR: C15.C, MICROSD.VDD, MICROSD_SWI.VOUT
SD_PWR_ON: MICROSD_SWI.EN, R26.A, TP6.TP; also elsewhere on the board

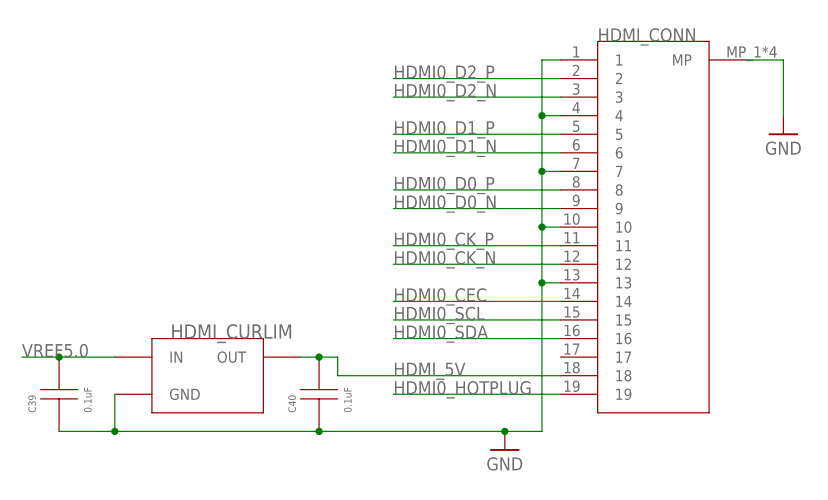
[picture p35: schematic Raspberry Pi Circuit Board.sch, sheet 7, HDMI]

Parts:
C39, C40: 0.1uF; CAP-603
HDMI_CONN: HDMI-2001-1-2-21-00-BK
HDMI_CURLIM: CURLIM-AP2331

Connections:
GND: C39.A, C40.A, HDMI_CONN.1, HDMI_CONN.4, HDMI_CONN.7, HDMI_CONN.10, HDMI_CONN.13, HDMI_CONN.MP_1 (MP), HDMI_CONN.MP_2 (MP), HDMI_CONN.MP_3 (MP), HDMI_CONN.MP_4 (MP), HDMI_CURLIM.GND; also elsewhere on the board
HDMI0_CEC: HDMI_CONN.14; also elsewhere on the board
HDMI0_CK_N: HDMI_CONN.12; also elsewhere on the board
HDMI0_CK_P: HDMI_CONN.11; also elsewhere on the board
HDMI0_D0_N: HDMI_CONN.9; also elsewhere on the board
HDMI0_D0_P: HDMI_CONN.8; also elsewhere on the board
HDMI0_D1_N: HDMI_CONN.6; also elsewhere on the board
HDMI0_D1_P: HDMI_CONN.5; also elsewhere on the board
HDMI0_D2_N: HDMI_CONN.3; also elsewhere on the board
HDMI0_D2_P: HDMI_CONN.2; also elsewhere on the board
HDMI0_HOTPLUG: HDMI_CONN.19; also elsewhere on the board
HDMI0_SCL: HDMI_CONN.15; also elsewhere on the board
HDMI0_SDA: HDMI_CONN.16; also elsewhere on the board
HDMI_5V: C40.C, HDMI_CONN.18, HDMI_CURLIM.OUT
VREF5.0: C39.C, HDMI_CURLIM.IN; also elsewhere on the board

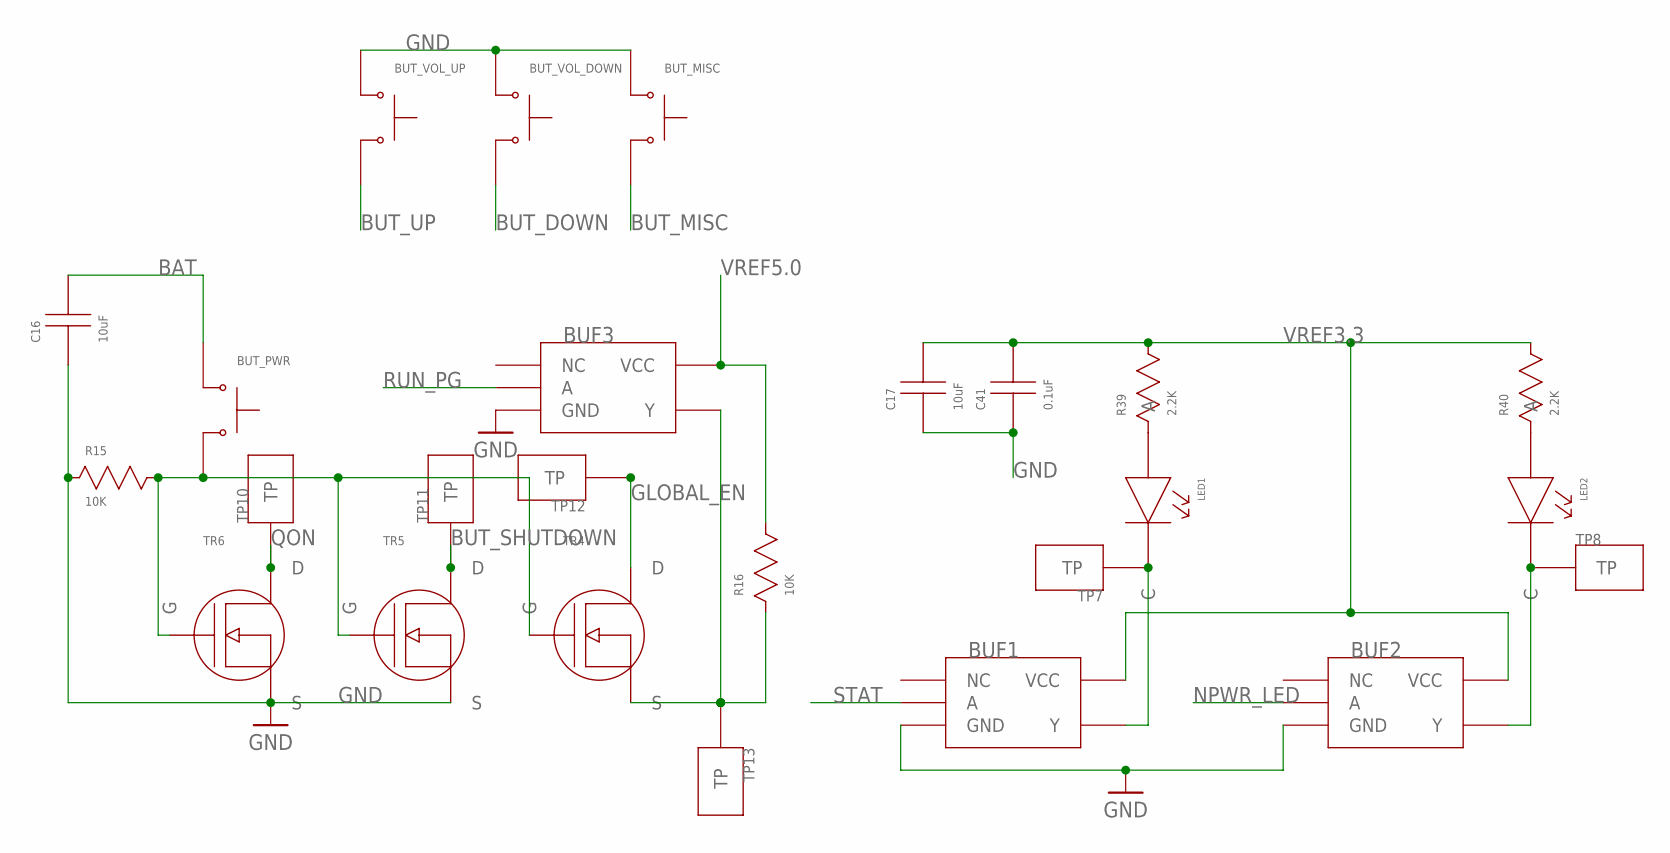
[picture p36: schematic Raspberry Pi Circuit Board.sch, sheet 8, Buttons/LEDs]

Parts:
BUF1, BUF2, BUF3: BUF-74LVC1G07
BUT_MISC: BUT-KSS331GLFS
BUT_PWR: BUT-KSS331GLFS
BUT_VOL_DOWN: BUT-KSS331GLFS
BUT_VOL_UP: BUT-KSS331GLFS
C16, C17: 10uF; CAP-603
C41: 0.1uF; CAP-603
LED1, LED2: LED-SM0805UWC
R15, R16: 10K; RES-603
R39, R40: 2.2K; RES-603
TP7, TP8, TP10, TP11, TP12, TP13: TESTPOINT
TR4, TR5, TR6: TRAN-DMG2302UKQ

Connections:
BAT: BUT_PWR.1, C16.C; also elsewhere on the board
BUT_DOWN: BUT_VOL_DOWN.2; also elsewhere on the board
BUT_MISC: BUT_MISC.2; also elsewhere on the board
BUT_SHUTDOWN: TP11.TP, TR5.D; also elsewhere on the board
BUT_UP: BUT_VOL_UP.2; also elsewhere on the board
GLOBAL_EN: TP12.TP, TR4.D; also elsewhere on the board
GND: BUF1.GND, BUF2.GND, BUF3.GND, BUT_MISC.1, BUT_VOL_DOWN.1, BUT_VOL_UP.1, C16.A, C17.A, C41.A, R15.A, TR5.S, TR6.S; also elsewhere on the board
unnamed: BUF1.Y, LED1.C, TP7.TP
unnamed: BUT_PWR.2, R15.C, TR4.G, TR5.G, TR6.G
unnamed: LED1.A, R39.A
unnamed: LED2.A, R40.A
unnamed: BUF2.Y, LED2.C, TP8.TP
unnamed: BUF3.Y, R16.A, TP13.TP, TR4.S
NPWR_LED: BUF2.A; also elsewhere on the board
QON: TP10.TP, TR6.D; also elsewhere on the board
RUN_PG: BUF3.A; also elsewhere on the board
STAT: BUF1.A; also elsewhere on the board
VREF3.3: BUF1.VCC, BUF2.VCC, C17.C, C41.C, R39.C, R40.C; also elsewhere on the board
VREF5.0: BUF3.VCC, R16.C; also elsewhere on the board

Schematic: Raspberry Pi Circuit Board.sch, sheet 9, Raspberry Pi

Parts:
RPI_PINS1-100, RPI_PINS101-200: CONN-DF40_CL0594-5437-8-00_2D

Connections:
AUDMUTE: RPI_PINS1-100.38; also elsewhere on the board
BITCLK_IN: RPI_PINS1-100.49; also elsewhere on the board
BUT_DOWN: RPI_PINS1-100.44; also elsewhere on the board
BUT_MISC: RPI_PINS1-100.39; also elsewhere on the board
BUT_SHUTDOWN: RPI_PINS1-100.37; also elsewhere on the board
BUT_UP: RPI_PINS1-100.40; also elsewhere on the board
DATA_IN: RPI_PINS1-100.25; also elsewhere on the board
DSI1_C_N: RPI_PINS101-200.87; also elsewhere on the board
DSI1_C_P: RPI_PINS101-200.89; also elsewhere on the board
DSI1_D0_N: RPI_PINS101-200.75; also elsewhere on the board
DSI1_D0_P: RPI_PINS101-200.77; also elsewhere on the board
DSI1_D1_N: RPI_PINS101-200.81; also elsewhere on the board
DSI1_D1_P: RPI_PINS101-200.83; also elsewhere on the board
ETH0_N: RPI_PINS1-100.10; also elsewhere on the board
ETH0_P: RPI_PINS1-100.12; also elsewhere on the board
ETH1_N: RPI_PINS1-100.6; also elsewhere on the board
ETH1_P: RPI_PINS1-100.4; also elsewhere on the board
ETH2_N: RPI_PINS1-100.9; also elsewhere on the board
ETH2_P: RPI_PINS1-100.11; also elsewhere on the board
ETH3_N: RPI_PINS1-100.5; also elsewhere on the board
ETH3_P: RPI_PINS1-100.3; also elsewhere on the board
ETH_LEDG: RPI_PINS1-100.15; also elsewhere on the board
ETH_LEDY: RPI_PINS1-100.17; also elsewhere on the board
FAN: RPI_PINS1-100.31; also elsewhere on the board
GAUGE_ALERT: RPI_PINS1-100.41; also elsewhere on the board
GLOBAL_EN: RPI_PINS1-100.99; also elsewhere on the board
GND: RPI_PINS1-100.1, RPI_PINS1-100.2, RPI_PINS1-100.7, RPI_PINS1-100.8, RPI_PINS1-100.13, RPI_PINS1-100.14, RPI_PINS1-100.22, RPI_PINS1-100.23, RPI_PINS1-100.32, RPI_PINS1-100.33, RPI_PINS1-100.42, RPI_PINS1-100.43, RPI_PINS1-100.52, RPI_PINS1-100.53, RPI_PINS1-100.59, RPI_PINS1-100.60, RPI_PINS1-100.65, RPI_PINS1-100.66, RPI_PINS1-100.71, RPI_PINS1-100.74, RPI_PINS1-100.98, RPI_PINS101-200.7, RPI_PINS101-200.8, RPI_PINS101-200.13, RPI_PINS101-200.14, RPI_PINS101-200.19, RPI_PINS101-200.20, RPI_PINS101-200.25, RPI_PINS101-200.26, RPI_PINS101-200.31, RPI_PINS101-200.32, RPI_PINS101-200.37, RPI_PINS101-200.38, RPI_PINS101-200.44, RPI_PINS101-200.50, RPI_PINS101-200.55, RPI_PINS101-200.56, RPI_PINS101-200.61, RPI_PINS101-200.62, RPI_PINS101-200.67, RPI_PINS101-200.68, RPI_PINS101-200.73, RPI_PINS101-200.74, RPI_PINS101-200.79, RPI_PINS101-200.80, RPI_PINS101-200.85, RPI_PINS101-200.86, RPI_PINS101-200.91, RPI_PINS101-200.92, RPI_PINS101-200.97, RPI_PINS101-200.98; also elsewhere on the board
HDMI0_CEC: RPI_PINS101-200.51; also elsewhere on the board
HDMI0_CK_N: RPI_PINS101-200.90; also elsewhere on the board
HDMI0_CK_P: RPI_PINS101-200.88; also elsewhere on the board
HDMI0_D0_N: RPI_PINS101-200.84; also elsewhere on the board
HDMI0_D0_P: RPI_PINS101-200.82; also elsewhere on the board
HDMI0_D1_N: RPI_PINS101-200.78; also elsewhere on the board
HDMI0_D1_P: RPI_PINS101-200.76; also elsewhere on the board
HDMI0_D2_N: RPI_PINS101-200.72; also elsewhere on the board
HDMI0_D2_P: RPI_PINS101-200.70; also elsewhere on the board
HDMI0_HOTPLUG: RPI_PINS101-200.53; also elsewhere on the board
HDMI0_SCL: RPI_PINS101-200.100; also elsewhere on the board
HDMI0_SDA: RPI_PINS101-200.99; also elsewhere on the board
INT: RPI_PINS1-100.45; also elsewhere on the board
NPWR_LED: RPI_PINS1-100.95; also elsewhere on the board
N_EXTRST: RPI_PINS1-100.100; also elsewhere on the board
N_RPIBOOT: RPI_PINS1-100.93; also elsewhere on the board
RP1.8: RPI_PINS1-100.88, RPI_PINS1-100.90
RP3.3: RPI_PINS1-100.78, RPI_PINS1-100.84, RPI_PINS1-100.86; also elsewhere on the board
RUN_PG: RPI_PINS1-100.92; also elsewhere on the board
SCL0: RPI_PINS1-100.80; also elsewhere on the board
SCL1: RPI_PINS1-100.56; also elsewhere on the board
SDA0: RPI_PINS1-100.82; also elsewhere on the board
SDA1: RPI_PINS1-100.58; also elsewhere on the board
SD_CLK: RPI_PINS1-100.57; also elsewhere on the board
SD_CMD: RPI_PINS1-100.62; also elsewhere on the board
SD_DAT0: RPI_PINS1-100.63; also elsewhere on the board
SD_DAT1: RPI_PINS1-100.67; also elsewhere on the board
SD_DAT2: RPI_PINS1-100.69; also elsewhere on the board
SD_DAT3: RPI_PINS1-100.61; also elsewhere on the board
SD_PWR_ON: RPI_PINS1-100.75; also elsewhere on the board
USB2_N: RPI_PINS101-200.3; also elsewhere on the board
USB2_P: RPI_PINS101-200.5; also elsewhere on the board
USBOTG: RPI_PINS101-200.1; also elsewhere on the board
VREF5.0: RPI_PINS1-100.77, RPI_PINS1-100.79, RPI_PINS1-100.81, RPI_PINS1-100.83, RPI_PINS1-100.85, RPI_PINS1-100.87; also elsewhere on the board
WORDSEL_IN: RPI_PINS1-100.26; also elsewhere on the board

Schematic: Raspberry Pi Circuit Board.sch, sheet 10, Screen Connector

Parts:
LCD_CONN: FPC-1-84952-5

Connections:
DSI1_C_N: LCD_CONN.11; also elsewhere on the board
DSI1_C_P: LCD_CONN.10; also elsewhere on the board
DSI1_D0_N: LCD_CONN.8; also elsewhere on the board
DSI1_D0_P: LCD_CONN.7; also elsewhere on the board
DSI1_D1_N: LCD_CONN.14; also elsewhere on the board
DSI1_D1_P: LCD_CONN.13; also elsewhere on the board
GND: LCD_CONN.3, LCD_CONN.6, LCD_CONN.9, LCD_CONN.12, LCD_CONN.15, LCD_CONN.MP_1 (MP), LCD_CONN.MP_2 (MP); also elsewhere on the board
RP3.3: LCD_CONN.1, LCD_CONN.2; also elsewhere on the board
SCL0: LCD_CONN.5; also elsewhere on the board
SDA0: LCD_CONN.4; also elsewhere on the board

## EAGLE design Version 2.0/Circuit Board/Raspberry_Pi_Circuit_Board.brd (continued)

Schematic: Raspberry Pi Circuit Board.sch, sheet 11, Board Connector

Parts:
BOARD_CONN_1: MEZZANINE-AXT630124

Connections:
AGND: BOARD_CONN_1.11; also elsewhere on the board
AUDSD: BOARD_CONN_1.14; also elsewhere on the board
D+1: BOARD_CONN_1.10; also elsewhere on the board
D+2: BOARD_CONN_1.8; also elsewhere on the board
D-1: BOARD_CONN_1.9; also elsewhere on the board
D-2: BOARD_CONN_1.7; also elsewhere on the board
ETH0_N: BOARD_CONN_1.22; also elsewhere on the board
ETH0_P: BOARD_CONN_1.23; also elsewhere on the board
ETH1_N: BOARD_CONN_1.20; also elsewhere on the board
ETH1_P: BOARD_CONN_1.21; also elsewhere on the board
ETH2_N: BOARD_CONN_1.18; also elsewhere on the board
ETH2_P: BOARD_CONN_1.19; also elsewhere on the board
ETH3_N: BOARD_CONN_1.16; also elsewhere on the board
ETH3_P: BOARD_CONN_1.17; also elsewhere on the board
ETH_LEDG: BOARD_CONN_1.24; also elsewhere on the board
ETH_LEDY: BOARD_CONN_1.25; also elsewhere on the board
GND: BOARD_CONN_1.15, BOARD_CONN_1.26, BOARD_CONN_1.27, BOARD_CONN_1.28, BOARD_CONN_1.29, BOARD_CONN_1.30, BOARD_CONN_1.MP_1 (MP), BOARD_CONN_1.MP_2 (MP), BOARD_CONN_1.MP_3 (MP), BOARD_CONN_1.MP_4 (MP); also elsewhere on the board
OUTL: BOARD_CONN_1.12; also elsewhere on the board
OUTR: BOARD_CONN_1.13; also elsewhere on the board
VBUS1: BOARD_CONN_1.2, BOARD_CONN_1.3, BOARD_CONN_1.4, BOARD_CONN_1.5, BOARD_CONN_1.6; also elsewhere on the board
VREF3.3: BOARD_CONN_1.1; also elsewhere on the board

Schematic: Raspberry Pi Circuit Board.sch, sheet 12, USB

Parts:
C1: 100uF; CAP-603
C18, C19, C20, C21: 10uF; CAP-603
C42, C43: 0.1uF; CAP-603
C52, C53: 27pF; CAP-603
CLK_24M: CLK-ECS-240
R23, R24: 2.2K; RES-603
R27: 12K; RES-603
R28: 15K; RES-603
R30, R31, R32, R33: 36K; RES-603
RPI_BOOT_SW: DIP-A6TN-1104
TP14, TP15: TESTPOINT
USB_CURLIM: CURLIM-AP22653W6
USB_HUB: USBPORT-USB2514BT-I/M2
USB_IN: USB-USB3131-30-0230-A
USB_POE: POE_PROT-TPD4EUSB30DQAR
USB_SWI: USB_SWITCH-FSUSB42-D

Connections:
D+1: USB_HUB.4; also elsewhere on the board
D+2: USB_HUB.7; also elsewhere on the board
D-1: USB_HUB.3; also elsewhere on the board
D-2: USB_HUB.6; also elsewhere on the board
GND: C1.A, C18.A, C19.A, C20.A, C21.A, C42.A, C43.A, C52.A, C53.A, CLK_24M.GND_1 (GND), CLK_24M.GND_2 (GND), R24.C, R27.C, R28.A, R30.C, R31.C, R32.C, R33.C, RPI_BOOT_SW.2, USB_CURLIM.GND, USB_HUB.37, USB_IN.GND, USB_IN.MP_1 (MP), USB_IN.MP_2 (MP), USB_POE.GND_1 (GND), USB_POE.GND_2 (GND), USB_SWI./OE, USB_SWI.GND; also elsewhere on the board
unnamed: R32.A, USB_HUB.28
unnamed: R28.C, USB_CURLIM.ILIM
unnamed: R31.A, USB_HUB.22
unnamed: R30.A, USB_HUB.24
unnamed: R23.A, TP15.TP, USB_IN.VBUS
unnamed: C53.C, CLK_24M.OUT/IN, USB_HUB.32
unnamed: C52.C, CLK_24M.IN/OUT, USB_HUB.33
unnamed: R33.A, USB_HUB.25
unnamed: R27.A, USB_HUB.35
N_EXTRST: USB_HUB.26; also elsewhere on the board
N_OCS1: USB_CURLIM.NFAULT, USB_HUB.13, USB_HUB.17, USB_HUB.19, USB_HUB.21
N_RPIBOOT: RPI_BOOT_SW.1; also elsewhere on the board
PWR1: USB_CURLIM.EN, USB_HUB.12
TD+: USB_HUB.2; also elsewhere on the board
TD-: USB_HUB.1; also elsewhere on the board
USB2_N: USB_SWI.D-; also elsewhere on the board
USB2_P: USB_SWI.D+; also elsewhere on the board
USBD_N: USB_IN.D+, USB_POE.D2+, USB_SWI.HSD2+
USBD_P: USB_IN.D-, USB_POE.D2-, USB_SWI.HSD2-
USBH_N: USB_HUB.30, USB_SWI.HSD1-
USBH_P: USB_HUB.31, USB_SWI.HSD1+
USBOTG: R23.C, R24.A, USB_SWI.SEL; also elsewhere on the board
VBUS1: C1.C, C21.C, TP14.TP, USB_CURLIM.OUT; also elsewhere on the board
VREF3.3: C18.C, C19.C, C42.C, C43.C, USB_HUB.5, USB_HUB.10, USB_HUB.15, USB_HUB.23, USB_HUB.27, USB_HUB.29, USB_HUB.36, USB_SWI.VCC; also elsewhere on the board
VREF5.0: C20.C, USB_CURLIM.IN; also elsewhere on the board

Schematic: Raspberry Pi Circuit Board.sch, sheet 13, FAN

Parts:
C44: 0.1uF; CAP-603
D3: DIODE-X3-WLB1608-2
FAN_CONN: CONN-282834-2
R19: 10K; RES-603
TP16: TESTPOINT
TR3: TRAN-DMG2302UKQ

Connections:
FAN: R19.C, TP16.TP, TR3.G; also elsewhere on the board
GND: C44.A, R19.A, TR3.S; also elsewhere on the board
unnamed: D3.A, FAN_CONN.2, TR3.D
VREF3.3: C44.C, D3.C, FAN_CONN.1; also elsewhere on the board

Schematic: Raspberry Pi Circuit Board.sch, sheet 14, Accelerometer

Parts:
ACCEL: MMA8451; MMA845X_QFN_16MM
C45: 0.1uF; CAP-603
R20: 10K; RES-603

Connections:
GND: ACCEL.5 (GND), ACCEL.10 (GND), ACCEL.12 (GND), C45.A; also elsewhere on the board
unnamed: ACCEL.2 (BYP), C45.C
SA0: ACCEL.7 (SA0), R20.A
SCL1: ACCEL.4 (SCL); also elsewhere on the board
SDA1: ACCEL.6 (SDA); also elsewhere on the board
VREF3.3: ACCEL.1 (VDDIO), ACCEL.14 (VDD), R20.C; also elsewhere on the board

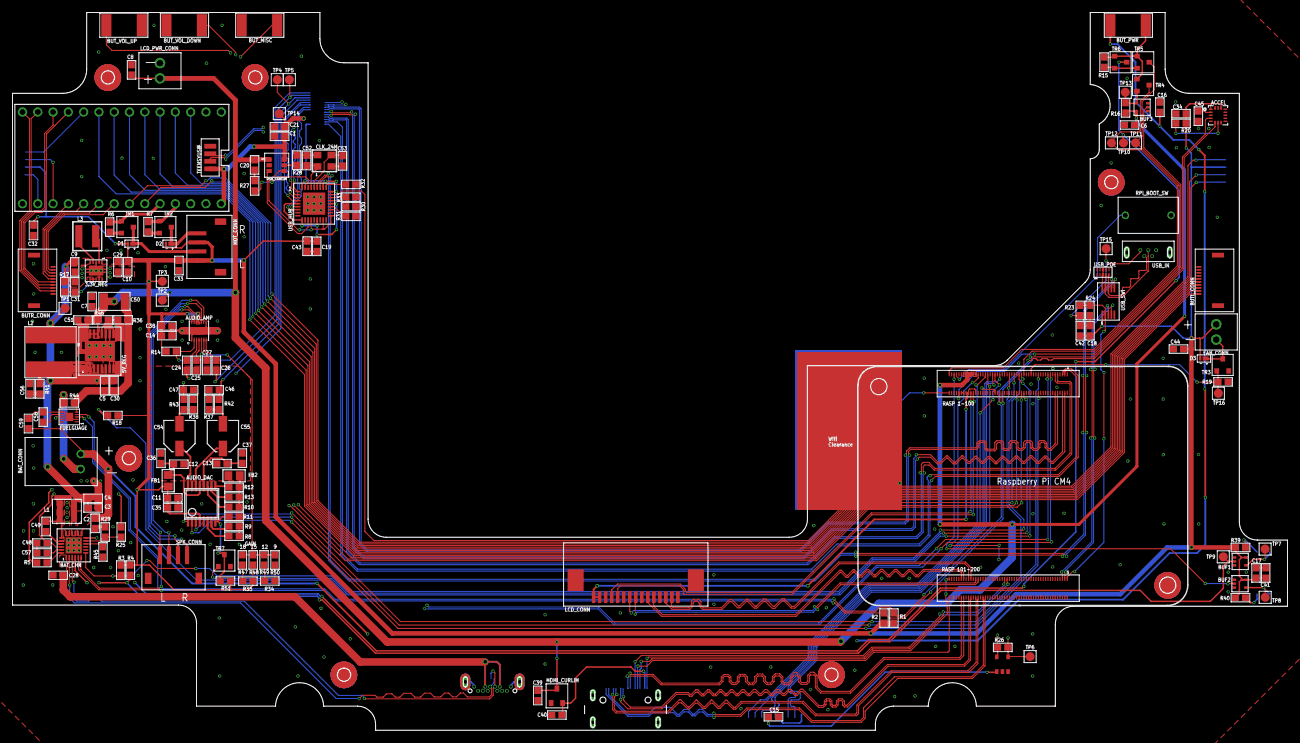
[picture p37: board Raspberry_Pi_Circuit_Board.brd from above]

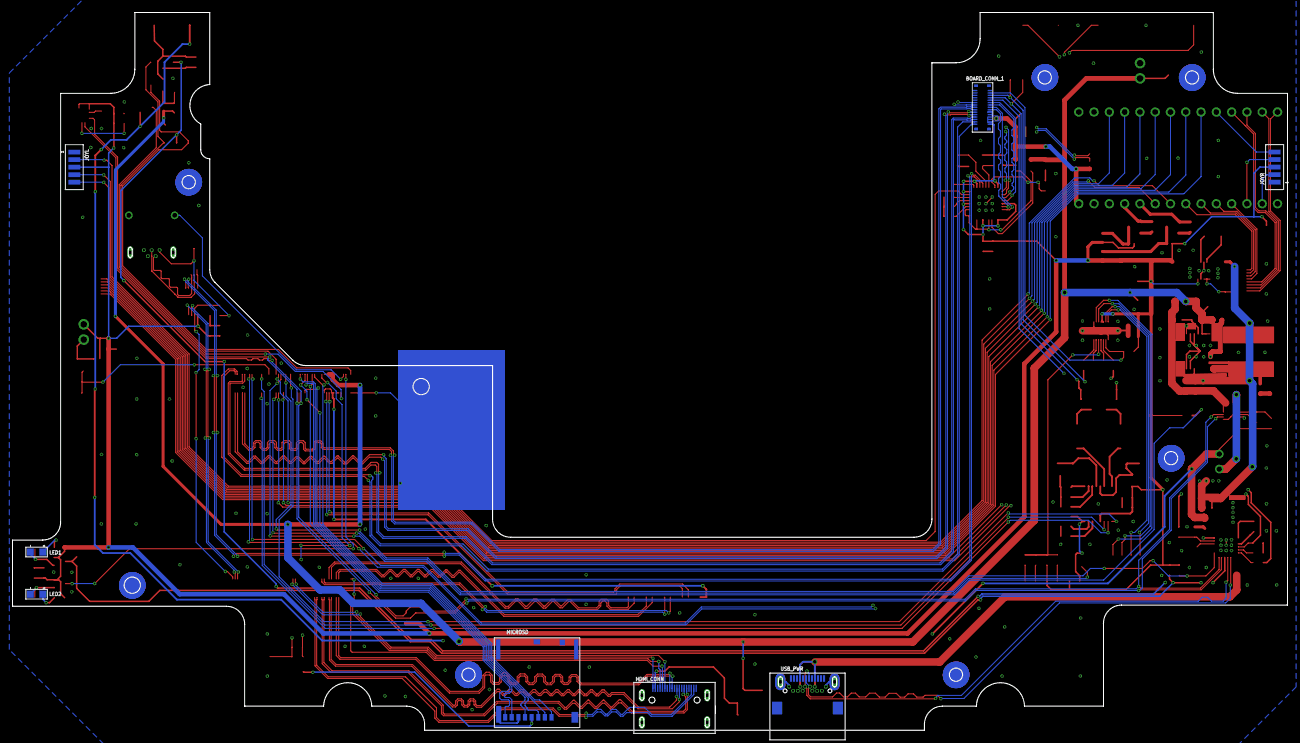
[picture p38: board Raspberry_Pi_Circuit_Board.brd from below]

Board: 4 copper layers, 211.9 x 119.3 mm, 180 parts (8 on the bottom side), 169 nets.

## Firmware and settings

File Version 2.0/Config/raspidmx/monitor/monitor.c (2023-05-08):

//-------------------------------------------------------------------------
//
// The MIT License (MIT)
//
// Copyright (c) 2013 Andrew Duncan
//
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
//-------------------------------------------------------------------------

#define _GNU_SOURCE

#include <assert.h>
#include <ctype.h>
#include <signal.h>
#include <stdbool.h>
#include <stdio.h>
#include <stdlib.h>
#include <strings.h>
#include <unistd.h>
//#include <pigpio.h>
#include <wiringPi.h>
#include <wiringPiI2C.h>
#include <alsa/asoundlib.h>
#include <sys/reboot.h>

#include "backgroundLayer.h"
#include "imageLayer.h"
#include "key.h"
#include "loadpng.h"
#include "bcm_host.h"

#ifndef ICON_BUF
#define ICON_BUF 200
#endif

#ifndef MAX_BUF
#define MAX_BUF 400
#endif

//-------------------------------------------------------------------------

#define NDEBUG

//-------------------------------------------------------------------------

const char *program = NULL;
char iconpath[ICON_BUF] = "/usr/local/bin/overlay_icons/";
//char iconpath[ICON_BUF];

char env_icons[3][MAX_BUF];
char wifi_icons[6][MAX_BUF];
char bt_icons[2][MAX_BUF];
char bar_icons[3][MAX_BUF];
char critical_battery_icon[MAX_BUF];
char battery_icons[10][MAX_BUF];
char color[] = "white";
char wifi_carrier[] = "/sys/class/net/wlan0/carrier"; // 1 when wifi connected, 0 when disconnected and/or ifdown
char wifi_linkmode[] = "/sys/class/net/wlan0/link_mode"; // 1 when ifup, 0 when ifdown
char bt_devices_dir[] = "/sys/class/bluetooth";
char backlight[] = "/sys/class/backlight/rpi_backlight/brightness";
char env_cmd[] = "vcgencmd get_throttled";
char temp_cmd[] = "vcgencmd measure_temp";

int dpi = 24;
int fan_on_temp = 60;
int battery_index = -1;
int wifi_index = -1;
int bt_index = -1;
int under_voltage = 0;
int freq_capped = 0;
int throttled = 0;
int critical_shutdown = 0;
int percent_levels[9] = {5, 10, 20, 30, 50, 60, 80, 90, 100};
char battery_level[] = "blah";

int pmin = 2;
uint32_t displayNumber = 0;
uint32_t powerButtonTime = 2000000;
uint32_t volbriBarTime = 3000000;
uint32_t miscButtonTime = 2000000;
uint32_t incdecButtonTime = 500000;
uint32_t criticalShutdownTime = 60000000;
uint32_t fanMinTime = 60000000;

int battery_charger_handle = 0;
int fuel_gauge_handle = 0;

volatile int display_brightness = 0;
volatile int display_volume = 0;
volatile uint32_t display_tick = 0;

volatile int decrease_pressed = 0;
volatile uint32_t decrease_tick = 0;
volatile int increase_pressed = 0;
volatile uint32_t increase_tick = 0;
volatile int misc_pressed = 0;
volatile int misc_alt = 0;
volatile uint32_t misc_tick = 0;
volatile int power_pressed = 0;
volatile uint32_t power_tick = 0;
volatile uint32_t critical_shutdown_tick = 0;

IMAGE_LAYER_T critical_battery_img;
IMAGE_LAYER_T battery_img[10];
IMAGE_LAYER_T wifi_img[6];
IMAGE_LAYER_T bluetooth_img[2];
IMAGE_LAYER_T under_voltage_img;
IMAGE_LAYER_T freq_capped_img;
IMAGE_LAYER_T throttled_img;
IMAGE_LAYER_T volume_bar_img;
IMAGE_LAYER_T brightness_bar_img;
IMAGE_LAYER_T dot_img;

DISPMANX_DISPLAY_HANDLE_T display;
DISPMANX_UPDATE_HANDLE_T update;
DISPMANX_MODEINFO_T info;

snd_mixer_t* handle = NULL;
snd_mixer_elem_t* elem = NULL;

//-------------------------------------------------------------------------

volatile bool run = true;
volatile bool shutdown = false;
volatile bool restart = false;

void gpioISR7();
void gpioISR8();
void gpioISR9();
void gpioISR10();
//void gpioISR(int gpio, int level, uint32_t tick);

//-------------------------------------------------------------------------

static void
signalHandler(
	int signalNumber)
{
	switch (signalNumber)
	{
		case SIGINT:
		case SIGTERM:

			run = false;
			break;
	};
}

//-------------------------------------------------------------------------

void setupDisplay()
{
	if (signal(SIGINT, signalHandler) == SIG_ERR)
	{
		perror("installing SIGINT signal handler");
		exit(EXIT_FAILURE);
	}

	//---------------------------------------------------------------------

	if (signal(SIGTERM, signalHandler) == SIG_ERR)
	{
		perror("installing SIGTERM signal handler");
		exit(EXIT_FAILURE);
	}

	//---------------------------------------------------------------------

	bcm_host_init();

	//---------------------------------------------------------------------

	display = vc_dispmanx_display_open(displayNumber);
	assert(display != 0);

	//---------------------------------------------------------------------

	int result = vc_dispmanx_display_get_info(display, &info);
	assert(result == 0);
}

void setupFiles()
{
	char levels[9][MAX_BUF] = {"alert_red", "alert", "20", "30", "50", "60", "80", "90", "full" };

	//getcwd(iconpath, ICON_BUF);
	//strcat(iconpath, "/overlay_icons/");

	for (int i = 0; i < 9; i++)
		sprintf(battery_icons[i], "%s%s%s%s%s%s%d%s", iconpath, "twotone_battery_", levels[i], "_", color, "_",  dpi, "dp.png");
	sprintf(battery_icons[9], "%s%s%s%s%d%s", iconpath, "twotone_battery_charging_", color, "_",  dpi, "dp.png");

	sprintf(env_icons[0], "%s%s%d%s", iconpath, "flash_", dpi, "dp.png");
	sprintf(env_icons[1], "%s%s%d%s", iconpath, "thermometer_", dpi, "dp.png");
	sprintf(env_icons[2], "%s%s%d%s", iconpath, "thermometer-lines_", dpi, "dp.png");

	sprintf(wifi_icons[0], "%s%s%s%s%d%s", iconpath, "twotone_signal_wifi_off_", color, "_", dpi, "dp.png");
	sprintf(wifi_icons[1], "%s%s%s%s%d%s", iconpath, "twotone_signal_wifi_0_bar_", color, "_", dpi, "dp.png");
	sprintf(wifi_icons[2], "%s%s%s%s%d%s", iconpath, "twotone_signal_wifi_1_bar_", color, "_", dpi, "dp.png");
	sprintf(wifi_icons[3], "%s%s%s%s%d%s", iconpath, "twotone_signal_wifi_2_bar_", color, "_", dpi, "dp.png");
	sprintf(wifi_icons[4], "%s%s%s%s%d%s", iconpath, "twotone_signal_wifi_3_bar_", color, "_", dpi, "dp.png");
	sprintf(wifi_icons[5], "%s%s%s%s%d%s", iconpath, "twotone_signal_wifi_4_bar_", color, "_", dpi, "dp.png");

	sprintf(bt_icons[0], "%s%s%s%s%d%s", iconpath, "twotone_bluetooth_", color, "_", dpi, "dp.png");
	sprintf(bt_icons[1], "%s%s%s%s%d%s", iconpath, "twotone_bluetooth_disabled_", color, "_", dpi, "dp.png");

	sprintf(bar_icons[0], "%s%s%s%s%d%s", iconpath, "volume_bar_", color, "_", dpi, "dp.png");
	sprintf(bar_icons[1], "%s%s%s%s%d%s", iconpath, "brightness_bar_", color, "_", dpi, "dp.png");
	sprintf(bar_icons[2], "%s%s%s%s%d%s", iconpath, "dot_", color, "_", dpi, "dp.png");

	sprintf(critical_battery_icon, "%s%s", iconpath, "alert-outline-red.png");
}

void setupFuelGauge()
{
	//fuel_gauge_handle = i2cOpen(1, 0x36, 0);
	//i2cWriteWordData(fuel_gauge_handle, 0x18, 0x1770);
	//i2cWriteWordData(fuel_gauge_handle, 0x45, 0x0177);
	//i2cWriteWordData(fuel_gauge_handle, 0xDB, 0x8000);

	fuel_gauge_handle = wiringPiI2CSetup(0x36);
	wiringPiI2CWriteReg16(fuel_gauge_handle, 0x18, 0x1770);
	wiringPiI2CWriteReg16(fuel_gauge_handle, 0x45, 0x0177);
	wiringPiI2CWriteReg16(fuel_gauge_handle, 0xDB, 0x8000);
}

void setupBatteryCharger()
{
	//battery_charger_handle = i2cOpen(1, 0x6a, 0);
	//i2cWriteByteData(battery_charger_handle, 0x04, 0x18); // set charge current
	//i2cWriteByteData(battery_charger_handle, 0x03, 0x30); // set min sys voltage
	//i2cWriteByteData(battery_charger_handle, 0x02, 0x7D); // enable battery read
	//i2cWriteByteData(battery_charger_handle, 0x07, 0x8D); // disable watchdog timer

	battery_charger_handle = wiringPiI2CSetup(0x6a);
	wiringPiI2CWriteReg8(battery_charger_handle, 0x04, 0x18); // set charge current
	wiringPiI2CWriteReg8(battery_charger_handle, 0x03, 0x30); // set min sys voltage
	wiringPiI2CWriteReg8(battery_charger_handle, 0x02, 0x7D); // enable battery read
	wiringPiI2CWriteReg8(battery_charger_handle, 0x07, 0x8D); // disable watchdog timer
}

void setupAudio()
{
	snd_mixer_selem_id_t* sid;
	const char* card = "sysdefault";
	const char* selem_name = "PCM";

	snd_mixer_open(&handle, 0);
	snd_mixer_attach(handle, card);
	snd_mixer_selem_register(handle, NULL, NULL);
	snd_mixer_load(handle);

	snd_mixer_selem_id_alloca(&sid);
	snd_mixer_selem_id_set_index(sid, 0);
	snd_mixer_selem_id_set_name(sid, selem_name);

	elem = snd_mixer_find_selem(handle, sid);
}

void setupButtons()
{
	//wiringPiISR(7, INT_EDGE_BOTH, &gpioISR7);
	//wiringPiISR(8, INT_EDGE_BOTH, &gpioISR8);
	//wiringPiISR(9, INT_EDGE_BOTH, &gpioISR9);
	//wiringPiISR(10, INT_EDGE_BOTH, &gpioISR10);
	//gpioSetISRFunc(7, EITHER_EDGE, 0, &gpioISR);
	//gpioSetISRFunc(8, EITHER_EDGE, 0, &gpioISR);
	//gpioSetISRFunc(9, EITHER_EDGE, 0, &gpioISR);
	//gpioSetISRFunc(10, EITHER_EDGE, 0, &gpioISR);
}

//------------------------------------------------------------------------------

IMAGE_LAYER_T createImageLayer(char* fileName, int layer)
{
	IMAGE_LAYER_T image;

	// Load image from path
	if (loadPng(&(image.image), fileName) == false)
	{
		fprintf(stderr, "unable to load %s\n", fileName);
		exit(EXIT_FAILURE);
	}

	createResourceImageLayer(&image, layer);

	return image;
}

void addImage(IMAGE_LAYER_T* img, int x, int y)
{
	update = vc_dispmanx_update_start(displayNumber);
	assert(update != 0);

	addElementImageLayerOffset(img, x, y, display, update);

	int result = vc_dispmanx_update_submit_sync(update);
	assert(result == 0);
}

void removeImage(IMAGE_LAYER_T* img)
{
	if (img->element == 0)
		return;

	update = vc_dispmanx_update_start(displayNumber);
	assert(update != 0);

	int result = vc_dispmanx_element_remove(update, img->element);
	assert(result == 0);

	result = vc_dispmanx_update_submit_sync(update);
	assert(result == 0);
}

void moveImage(IMAGE_LAYER_T* img, int x, int y)
{
	update = vc_dispmanx_update_start(displayNumber);
	assert(update != 0);

	moveImageLayer(img, x, y, update);

	int result = vc_dispmanx_update_submit_sync(update);
	assert(result == 0);
}

//------------------------------------------------------------------------------

double getBatteryVoltage()
{
	//int batteryVolt = i2cReadByteData(battery_charger_handle, 0x0E);
	int batteryVolt = wiringPiI2CReadReg8(battery_charger_handle, 0x0E);
	double voltage = ((batteryVolt >> 6) & 1) * 1280;
	voltage += ((batteryVolt >> 5) & 1) * 640;
	voltage += ((batteryVolt >> 4) & 1) * 320;
	voltage += ((batteryVolt >> 3) & 1) * 160;
	voltage += ((batteryVolt >> 2) & 1) * 80;
	voltage += ((batteryVolt >> 1) & 1) * 40;
	voltage += (batteryVolt & 1) * 20 + 2304;
	voltage /= 1000;
	if(voltage <= 0)
		return 3.0;
	return voltage;
}

int getChargingStatus()
{
	//int status = i2cReadByteData(battery_charger_handle, 0x0B);
	int status = wiringPiI2CReadReg8(battery_charger_handle, 0x0B);
	int charging = ((status >> 3) & 3);
	if (charging == 0)
		return 0; // discharging;
	else
		return 1; // charging
}

int getBatteryIndex(int percent)
{
	int status = getChargingStatus();

	if(status == 0)
	{
		for(int i = 0; i < 9; i++)
		{
			if (percent <= percent_levels[i])
				return i;
		}
	}
	return 9;
}

int getBatteryPercent()
{
	//uint16_t percent = i2cReadWordData(fuel_gauge_handle, 0x06);
	uint16_t percent = wiringPiI2CReadReg16(fuel_gauge_handle, 0x06);
	return percent >> 8;
}

void displayBattery(uint32_t tick)
{
	int status = getChargingStatus();
	int percent = getBatteryPercent();
	int index = getBatteryIndex(percent);

	if (critical_shutdown == 0 && percent < pmin && status == 0)
	{
		addImage(&critical_battery_img,
			 (info.width - critical_battery_img.image.width) / 2,
			 (info.height - critical_battery_img.image.height) / 2);
		critical_shutdown = 1;
		critical_shutdown_tick = tick;
	}

	if (index != battery_index)
	{
		addImage(&battery_img[index], info.width - battery_img[index].image.width, 0);
		removeImage(&battery_img[battery_index]);
		battery_index = index;
	}
}

//-------------------------------------------------------------------------

int getVolumeLevel()
{
	long volume = 0;
	snd_mixer_selem_get_playback_volume(elem, SND_MIXER_SCHN_FRONT_LEFT, &volume);
	return volume;
}

void setVolumeLevel(int volume)
{
	snd_mixer_selem_set_playback_volume_all(elem, volume);
}

int getBrightnessLevel()
{
	char buf[4];
	FILE* fptr = fopen(backlight, "r");

	fgets(buf, 4, fptr);
	int brightness = atoi(buf);

	fclose(fptr);

	return brightness;
}

void setBrightnessLevel(int brightness)
{
	FILE* fptr = fopen(backlight, "w");

	fprintf(fptr, "%i", brightness);
	fclose(fptr);
}


void hideBar()
{
	if(display_volume == 1)
	{
		removeImage(&volume_bar_img);
		removeImage(&dot_img);
	}
	else if(display_brightness == 1)
	{
		removeImage(&brightness_bar_img);
		removeImage(&dot_img);
	}
	display_volume = 0;
	display_brightness = 0;
}

void displayVolumeBar(int volume)
{
	double dpi_d = dpi;
	int dotx = volume / 256.0 * (4.0 * dpi_d - dpi_d / 3.0) + dpi_d;

	if(display_volume == 1)
	{
		moveImage(&dot_img, dotx, 0);
	}
	else
	{
		if(display_brightness == 1)
		{
			removeImage(&brightness_bar_img);
			removeImage(&dot_img);
			display_brightness = 0;
		}
		addImage(&dot_img, dotx, 0);
		addImage(&volume_bar_img, 0, 0);
	}
	display_volume = 1;
	//display_tick = gpioTick();
	display_tick = micros();
}

void displayBrightnessBar(int brightness)
{
	double dpi_d = dpi;
	int dotx = brightness / 200.0 * (4.0 * dpi_d - dpi_d / 3.0) + dpi_d;

	if(display_brightness == 1)
	{
		moveImage(&dot_img, dotx, 0);
	}
	else
	{
		if(display_volume == 1)
		{
			removeImage(&volume_bar_img);
			removeImage(&dot_img);
			display_volume = 0;
		}
		addImage(&dot_img, dotx, 0);
		addImage(&brightness_bar_img, 0, 0);
	}
	display_brightness = 1;
	//display_tick = gpioTick();
	display_tick = micros();
}

//-------------------------------------------------------------------------

int getWifiLevel()
{
	FILE *fp = popen("iwconfig wlan0 | grep -i -w signal", "r");
	if (fp == NULL)
	{
		printf("failed to run command");
		exit(1);
	}

	char strength_str[6];
	char path[1000];
	int strength = 0;
	while (fgets(path, sizeof(path), fp) != NULL) {
		int index1 = rindex(path, '=') + 1 - path;
		int index2 = rindex(path, 'd') - path;
		memcpy(strength_str, &path[index1], index2 - index1);
	}
	pclose(fp);

	strength = atoi(strength_str);

	if (strength > -50)
		return 5;
	else if (strength > -65)
		return 4;
	else if (strength > -70)
		return 3;
	else if (strength > -80)
		return 2;
	else
		return 1;
}

void displayWifi()
{
	int index = -1;

	char buf[2];
	FILE* fptr = fopen(wifi_carrier, "r");
	fgets(buf, 2, fptr);
	fclose(fptr);

	int carrier_state = atoi(buf);
	if (carrier_state == 1)
	{
		index = getWifiLevel();
	}
	else
	{
		fptr = fopen(wifi_linkmode, "r");
		fgets(buf, 2, fptr);
		fclose(fptr);

		int linkmode = atoi(buf);
		if (linkmode == 1)
			index = 0;
	}

	if (index != wifi_index)
	{
		if (wifi_index != -1)
			removeImage(&wifi_img[wifi_index]);
		if (index != -1)
			addImage(&wifi_img[index], info.width - wifi_img[index].image.width - dpi, 0);

		wifi_index = index;
	}
}

//-------------------------------------------------------------------------

void displayBluetooth()
{

}

//-------------------------------------------------------------------------

int getCPUTemp()
{
	FILE *fp = popen(temp_cmd, "r");
	if (fp == NULL)
	{
		printf("failed to run command");
		exit(1);
	}

	char temp_str[6];
	char path[1000];
	while (fgets(path, sizeof(path), fp) != NULL) 
	{
		int index1 = rindex(path, '=') + 1 - path;
		int index2 = rindex(path, '\'') - path;
		memcpy(temp_str, &path[index1], index2 - index1);
	}
	pclose(fp);

	return atoi(temp_str);
}

void displayEnvironment()
{
	FILE *fp = popen(env_cmd, "r");
	if (fp == NULL)
	{
		printf("failed to run command");
		exit(1);
	}

	char env_str[6];
	char path[1000];
	while (fgets(path, sizeof(path), fp) != NULL) 
	{
		int index1 = rindex(path, 'x') + 1 - path;
		memcpy(env_str, &path[index1], 2);
	}
	pclose(fp);

	int env = atoi(env_str);
	int under_voltage_temp = env & 0x01;
	int freq_capped_temp = env & 0x02;
	int throttled_temp = env & 0x04;

	if (under_voltage != under_voltage_temp)
	{
		under_voltage = under_voltage_temp;
		if (under_voltage > 0)
			addImage(&under_voltage_img, info.width - under_voltage_img.image.width - dpi * 3, 0);
		else
			removeImage(&under_voltage_img);
	}

	if (freq_capped != freq_capped_temp)
	{
		freq_capped = freq_capped_temp;
		if (freq_capped > 0)
			addImage(&freq_capped_img, info.width - freq_capped_img.image.width - dpi * 4, 0);
		else
			removeImage(&freq_capped_img);
	}

	if (throttled != throttled_temp)
	{
		throttled = throttled_temp;
		if (throttled > 0)
			addImage(&throttled_img, info.width - throttled_img.image.width - dpi * 5, 0);
		else
			removeImage(&throttled_img);
	}
}

//-------------------------------------------------------------------------

void increase()
{
	if (misc_pressed == 1)
	{
		misc_alt = 1;
		int brightness = getBrightnessLevel();
		brightness = brightness + 10;
		if (brightness > 200)
			brightness = 200;
		setBrightnessLevel(brightness);
		displayBrightnessBar(brightness);
	}
	else
	{
		int volume = getVolumeLevel();
		volume = volume + 5;
		if(volume > 255)
			volume = 255;
		setVolumeLevel(volume);
		displayVolumeBar(volume);
	}
}

void decrease()
{
	if (misc_pressed == 1)
	{
		misc_alt = 1;
		int brightness = getBrightnessLevel();
		brightness = brightness - 10;
		if (brightness < 0)
			brightness = 0;
		setBrightnessLevel(brightness);
		displayBrightnessBar(brightness);
	}
	else
	{
		int volume = getVolumeLevel();
		volume = volume - 5;
		if(volume < 0)
			volume = 0;
		setVolumeLevel(volume);
		displayVolumeBar(volume);
	}
}

void restart_cmd()
{
	FILE *fp = popen("sudo /usr/local/bin/multi_switch.sh --es-pid", "r");
	if (fp == NULL)
	{
		printf("failed to run command");
		exit(1);
	}

	int pidRunning = 1;
	char path[1000];
	while (fgets(path, sizeof(path), fp) != NULL) {
		pidRunning = atoi(path);
	}
	pclose(fp);

	if(pidRunning == 0)
		system("sudo reboot");
	else
		system("sudo /usr/local/bin/multi_switch.sh --es-reboot");
}

void shutdown_cmd()
{
	//int status = i2cReadByteData(battery_charger_handle, 0x0B);
	int status = wiringPiI2CReadReg8(battery_charger_handle, 0x0B);
	status = status >> 5;
	if (status == 0)
		wiringPiI2CWriteReg8(battery_charger_handle, 0x09, 0x6c); // shut down power to system
		//i2cWriteByteData(battery_charger_handle, 0x09, 0x6c); // shut down power to system

	FILE *fp = popen("sudo /usr/local/bin/multi_switch.sh --es-pid", "r");
	if (fp == NULL)
	{
		printf("failed to run command");
		exit(1);
	}

	int pidRunning = 1;
	char path[1000];
	while (fgets(path, sizeof(path), fp) != NULL) {
		pidRunning = atoi(path);
	}
	pclose(fp);

	if(pidRunning == 0)
		system("sudo shutdown -h now");
	else
		system("sudo /usr/local/bin/multi_switch.sh --es-poweroff");
}

void gpioISR7()
{
	uint32_t tick = micros();
	uint32_t tick_diff = 0;
	if (power_pressed == 0)
	{
		power_pressed = 1;
		power_tick = tick;
	}
	else
	{
		power_pressed = 0;
		tick_diff = tick - power_tick;
		if(tick_diff < powerButtonTime)
		{
			run = false;
			restart = true;
		}
	}
}

void gpioISR8()
{
	uint32_t tick = micros();
	if(misc_pressed == 0)
	{
		misc_pressed = 1;
		misc_tick = tick;
	}
	else
	{
		misc_pressed = 0;
		misc_alt = 0;
		misc_tick = 0;
	}
}

void gpioISR9()
{
	uint32_t tick = micros();
	if(increase_pressed == 0)
	{
		increase_pressed = 1;
		increase_tick = tick;
		increase();
	}
	else
	{
		increase_pressed = 0;
		increase_tick = 0;
	}
}
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
int main(int argc, char *argv[])
{
	//gpioInitialise();

	int result = 0;
	int cpuTemp = 0;
	int sleepMilliseconds = 100;
	uint32_t tick = 0;
	uint32_t previousTick = 0;
	uint32_t tickDiff = 0;
	int fanTick = 0;
	int fanState = 0;

	wiringPiSetupGpio();

	setupFiles();
	setupFuelGauge();
	setupBatteryCharger();
	setupDisplay();
	setupAudio();
	setupButtons();

	loadInitialImages();

	previousTick = micros();
	tick = previousTick;

	while(run)
	{
		cpuTemp = getCPUTemp();
		tick = micros();
		tickDiff = tick - previousTick;
		if (tickDiff > 1000000)
		{
			previousTick = tick;
			displayBattery(tick);
			displayWifi();
			displayEnvironment();

			if (fanTick > 0)
				fanTick = fanTick - tickDiff;
		}

		// check volume bar and hide if out for more then 3 seconds
		if ((display_volume == 1 || display_brightness == 1) && tick - display_tick >= volbriBarTime)
			hideBar();

		// check to see if the misc button has been held down but not being used for alternate increase and decrease buttons
		if (misc_pressed == 1 && misc_alt == 0 && tick - misc_tick >= miscButtonTime)
		{
			system("sudo ifconfig wlan0 down");
			system("sudo ifconfig wlan0 up");
			misc_pressed = 0;
			misc_tick = 0;
		}

		// check if the power button is held down for the power off
		if (power_pressed == 1 && tick - power_tick >= powerButtonTime)
		{
			power_pressed = 0;
			shutdown = true;
			break;
		}

		// check to see if the increase is held down
		if (increase_pressed == 1 && tick - increase_tick >= incdecButtonTime)
		{
			display_tick = tick;
			increase();
		}

		// check to see if the decrease is held down
		if (decrease_pressed == 1 && tick - decrease_tick >= incdecButtonTime)
		{
			display_tick = tick;
			decrease();
		}

		// check to see if the critical shutdown is going
		if (critical_shutdown == 1 && tick - critical_shutdown_tick >= criticalShutdownTime)
		{
			critical_shutdown = 0;
			shutdown = true;
			break;
		}

		// turn on fan if the cpuTemp is above the fan limit
		if (cpuTemp > fan_on_temp)
			fanTick = fanMinTime;

		if (fanState == 0 && fanTick > 0)
		{
			digitalWrite(12, 1);
			fanState = 1;
		}
		else if (fanState == 1 && fanTick <= 0)
		{
			digitalWrite(12, 0);
			fanState = 0;
		}

		updateGPIO();

		usleep(sleepMilliseconds * 1000);
	}


	destroyImageLayer(&critical_battery_img);
	for (int i = 0; i < 10; i++)
		destroyImageLayer(&battery_img[i]);
	destroyImageLayer(&volume_bar_img);
	destroyImageLayer(&brightness_bar_img);
	destroyImageLayer(&dot_img);

	result = vc_dispmanx_display_close(display);
	assert(result == 0);


 	snd_mixer_close(handle);

	if (shutdown == true)
		shutdown_cmd();
	else if (restart == true)
		restart_cmd();

	//gpioTerminate();
	return 0;
}

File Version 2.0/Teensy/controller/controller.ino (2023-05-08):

#include <XInput.h>

uint8_t smallRumbleCounter = 0;
uint8_t bigRumbleCounter = 0;

void setup() {
  pinMode(1, INPUT_PULLUP);  
  pinMode(2, INPUT_PULLUP);  
  pinMode(3, INPUT_PULLUP);  
  pinMode(4, INPUT_PULLUP);  
  pinMode(5, INPUT_PULLUP);  
  pinMode(6, INPUT_PULLUP);  
  pinMode(7, INPUT_PULLUP);  
  pinMode(8, INPUT_PULLUP);  
  pinMode(9, INPUT_PULLUP);  
  pinMode(10, INPUT_PULLUP);  
  pinMode(11, INPUT_PULLUP);  
  pinMode(12, INPUT_PULLUP);  
  pinMode(16, INPUT_PULLUP);  
  pinMode(17, INPUT_PULLUP);  
  pinMode(18, INPUT_PULLUP);  
  pinMode(19, INPUT_PULLUP);  

  pinMode(22, OUTPUT);
  pinMode(23, OUTPUT);

  analogWriteFrequency(22, 187500);
  analogWriteFrequency(23, 187500);

  XInput.begin();

  XInput.setTriggerRange(0, 1);
  XInput.setJoystickRange(300, 740);
}


void loop() {
  boolean upPad = !digitalRead(3);
  boolean downPad = !digitalRead(2);
  boolean leftPad = !digitalRead(4);
  boolean rightPad = !digitalRead(5);

  boolean buttonA = !digitalRead(9);
  boolean buttonB = !digitalRead(18);
  boolean buttonX = !digitalRead(12);
  boolean buttonY = !digitalRead(19);
  boolean buttonLB = !digitalRead(7);
  boolean buttonRB = !digitalRead(16);
  boolean buttonL3 = !digitalRead(1);
  boolean buttonR3 = !digitalRead(8);
  boolean buttonStart = !digitalRead(11);
  boolean buttonSelect = !digitalRead(10);

  int buttonLT = !digitalRead(6);
  int buttonRT = !digitalRead(17);

  int leftStickX = analogRead(6);
  int leftStickY = analogRead(7);

  int rightStickX = analogRead(0);
  int rightStickY = analogRead(1);

  uint8_t bigRumble = XInput.getRumbleLeft();
  uint8_t smallRumble = XInput.getRumbleRight();
  uint8_t bigRumbleSet = 0;
  uint8_t smallRumbleSet = 0;

  XInput.setDpad(upPad, downPad, leftPad, rightPad);
  XInput.setJoystick(JOY_LEFT, leftStickX, leftStickY);
  XInput.setJoystick(JOY_RIGHT, rightStickX, rightStickY);

  XInput.setTrigger(TRIGGER_LEFT, buttonLT);
  XInput.setTrigger(TRIGGER_RIGHT, buttonRT);
    
  XInput.setButton(BUTTON_A, buttonA);
  XInput.setButton(BUTTON_B, buttonB);
  XInput.setButton(BUTTON_X, buttonX);
  XInput.setButton(BUTTON_Y, buttonY);
  XInput.setButton(BUTTON_LB, buttonLB);
  XInput.setButton(BUTTON_RB, buttonRB);
  XInput.setButton(BUTTON_L3, buttonL3);
  XInput.setButton(BUTTON_R3, buttonR3);
  XInput.setButton(BUTTON_START, buttonStart);
  XInput.setButton(BUTTON_BACK, buttonSelect);

  // Lower the rumble values for the motors in the handheld
  if (bigRumble > 25)
  {
    bigRumbleCounter = 0;
    bigRumbleSet = bigRumble / 8 + 45;
  }
  else
  {
    if (bigRumbleCounter > 10)
      bigRumbleSet = 0;
    else
      bigRumbleCounter = bigRumbleCounter + 1;
  }

  if (smallRumble > 25)
  {
    smallRumbleCounter = 0;
    smallRumbleSet = smallRumble / 8 + 45;
  }
  else
  {
    if (smallRumbleCounter > 10)
      smallRumbleSet = 0;
    else
      smallRumbleCounter = smallRumbleCounter + 1;
  }

  analogWrite(23, bigRumbleSet);
  analogWrite(22, smallRumbleSet);
  
  delay(5);
}

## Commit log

2021-03-10 Adding all of the files for the first prototype to the repository
    [Aegis BOM.xlsx, Back C.stl, Back L.stl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]
2021-03-10 Updating the Back.stl to the proper size
2021-03-10 Adding gerber files for the circuit boards
2021-03-10 renamed the ciruit board folder to "Circuit Board"
    [Raspberry_Pi_Circuit_Board.brd, Raspberry_Pi_Circuit_Board.sch, Raspberry_Pi_Circuit_Board_2.brd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]
2021-04-17 Updating the following:
    Changed the folder structure so that I can keep track of the previous versions
    Added a change log
    Made various software updates to fix errors and improve functionality
    [Aegis BOM.xlsx, Back C.stl, Back L.stl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]
2021-11-12 Added an fbx file for the case and updated some images
2021-11-12 Adding Fusion 360 Files of the case
2023-05-08 Adding the Version 2.0 with minor case and software changes. The Case changes are not required but make it more rigid for 3D Printing.
    [Aegis BOM.xlsx, Back C.stl, Back L.stl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]

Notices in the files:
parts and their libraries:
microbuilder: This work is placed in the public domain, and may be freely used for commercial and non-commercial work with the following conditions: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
